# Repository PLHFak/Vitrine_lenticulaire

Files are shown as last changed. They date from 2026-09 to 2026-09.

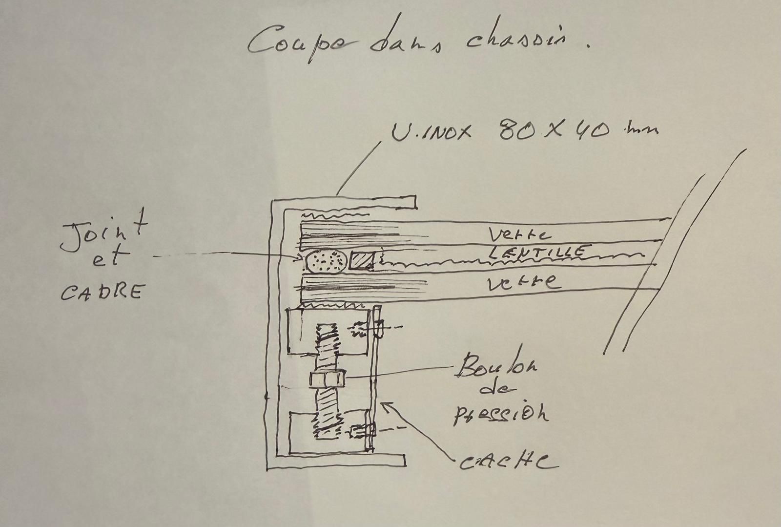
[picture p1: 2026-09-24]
img/croquis_260924.jpeg

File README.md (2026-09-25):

# La vitrine lenticulaire — Les Veilleurs

Note de principe et dossier de fabrication du double vitrage démontable de l'écran lenticulaire (site statique).

- `data.js` — tout le contenu : contexte, fiche, principe, montage, profil & vent, fournitures, points ouverts, documents, prompt CAO, journal
- `img/` — figures de principe, croquis, châssis v01, vues du STEP v00
- `docs/` — note v01 (PDF), note vent (MD), PDF cartouchés des schémas (`docs/pdf/`), CAO (`docs/cao/` : STEP v00 de J. Miceli, STL châssis v01), plans du socle
- `vercel.json` — déploiement Vercel (preset Other), noindex

Site : https://vitrine-lenticulaire.vercel.app (à importer sur Vercel depuis ce dépôt). Lien direct : https://vitrine-lenticulaire.vercel.app/?code=EVA

## Charte commune aux trois dossiers

Les trois sites (`Base_les_veilleurs`, `Vitrine_lenticulaire`, `Aquarium-K9`) partagent le même gabarit :

- `lv.css` et `lv.js` — styles, barre de titre (liens vers les trois dossiers, onglets de langue), cartouche technique, cartes « Documents ». **Ces deux fichiers doivent rester identiques dans les trois dépôts** : toute modification se recopie dans les deux autres.
- `data.js` — le seul fichier de contenu. Chaque texte est donné dans les quatre langues avec `L("fr","en","nl","de")` ; les schémas et plans restent légendés en français.
- `index.html` — gabarit et rendu des sections propres au dossier (ne porte pas de contenu).
- `build.py` — génère les vignettes (`docs/thumbs/`), les PDF avec cartouche des schémas (`docs/pdf/`), les PNG des plans (`docs/png/`) et `docs/sizes.js`. S'appuie sur `lv_build.py` (commun, identique dans les trois dépôts ; Pillow, reportlab, pdftoppm).

Langue : onglets FR / EN / NL / DE en haut de page, ou `?lang=en` dans le lien ; le choix est mémorisé dans le navigateur.

Accès : code `EVA` (côté client, `lv.js`), ou `?code=EVA` dans le lien. Pages en `noindex`.

## Mesure d'audience (chapitre « Fréquentation »)

- `api/hit.js` — reçoit les mesures du navigateur sur le même domaine que le site (rien vers un tiers ; échec silencieux). Pas d'IP ni de cookie : site, langue, page, document téléchargé, pays/ville (en-têtes Vercel), appareil, durée.
- `api/stats.js` — statistiques ; le code administrateur est vérifié dans la base (fonction `lv_stats`), jamais côté client.
- `api/_cfg.js` — URL et clé *anon* Supabase (variables Vercel `SUPABASE_URL` / `SUPABASE_ANON_KEY` prioritaires).
- `docs/lv_analytics.sql` — à exécuter une fois dans Supabase (tables `lv_hits`, `lv_config` avec le code administrateur, fonction `lv_stats`). Commun aux trois sites.
- Le chapitre apparaît en bas de page quand le site est ouvert avec le code administrateur (saisi au clavier ; il n'est jamais mis dans un lien). Les visites administrateur ne sont pas comptées.

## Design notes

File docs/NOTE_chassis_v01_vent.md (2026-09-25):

# Châssis vitrine lenticulaire — v01 et prise au vent (25-09-2026)

Transfert depuis le fil « base monobloc ». Fichiers dans ce dossier :
- `ecran_v00_100x40x3.stp` — STEP de Jacky (Inventor, 24-09-26) : tube 100×40×3, hors tout 1 890, montants 1 728 dont 528 traversants.
- `ecran_v00_vues.png` — filaire du STEP en 3 vues.
- `ecran_v01_U80x40.png` / `.stl` — châssis adapté : U 80×40×5 inox 316L, hors tout 1 820 × 1 220, verre 1 800 × 1 200, montants 1 720 dont 500 encastrés (réservation borgne 50×110×500, entraxe 1 780 — plan V00 à mettre à jour, 1 720 actuel).

## Profil
| Profil | W (cm³) | kg/m | Dispo |
|---|---|---|---|
| U 80×40×4 plié 316L | 14,7 | 4,8 | pliage sur mesure |
| **U 80×40×5 soudé laser 316L** | 17,7 | 5,9 | sur mesure, retenu |
| UPN 80 inox (80×45×6/8) | 26,5 | 8,6 | catalogue, plus lourd |

## Vent 220 km/h (61 m/s, q = 2,3 kPa, cf = 1,8 panneau isolé)
- Effort écran 9,6 kN à 0,66 m → 6,4 kNm ; par montant 4,8 kN / 3,2 kNm.
- Contraintes : U 4 mm 216 MPa (limite) ; U 5 mm 180 MPa (OK, 20 % de marge) ; UPN 80 120 MPa ; tube 100×40×3 162 MPa. Flèche en tête 7 mm (U 5 mm).
- Encastrement 500 mm : pression sur pierre ≈ 1,7 MPa, négligeable pour du Comblanchien.
- Bloc 6,7 t : renversement 12,5 kNm vs 62 kNm stabilisant → sécurité 5 ; glissement 33 kN vs 14 kN. Tient par sa masse.
- Verre : 55.2 recuit ≈ 23 MPa (limite) → prévoir feuilleté trempé (66.2 trempé ≈ 16 MPa).
- Prédimensionnement à confirmer par le bureau d'ossature.

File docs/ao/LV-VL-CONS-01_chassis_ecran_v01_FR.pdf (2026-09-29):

PROJET
LES VEILLEURS — Beaufort 27

ARTISTE · MAÎTRE D'ŒUVRE
Eva L'Hoest · +32 495 57 92 12 · eva.lhoest@gmail.com

ASSISTANT ÉLECTROMÉCANIQUE
Gioacchino Miceli · +32 497 84 45 10 gioacchino.miceli@thefaktory.com

Production Office
Eva L'Hoest / EHLAB SRL · eva.production.bx@gmail.com

DOCUMENT
Châssis de l'écran — consultation

OBJET
Châssis tube inox 316L, deux montants scellés

N° DOCUMENT
LV-VL-CONS-01

RÉVISION
v01.1

DATE · HEURE
29-09-2026 · 23:56

STATUT
CONSULTATION

PAGE
1 / 5

© Eva L'Hoest 2026 — Confidentiel. Reproduction, diffusion ou usage hors de cette consultation interdits sans accord écrit de l'artiste. Cotes non contractuelles.

## Les Veilleurs — Châssis de l'écran lenticulaire

Dossier de consultation v01 · septembre 2026 · métallerie inox — demande d'avis constructif et d'offre de prix

### 1. De quoi s'agit-il

Une œuvre d'art permanente sur la côte belge (Beaufort 27, mer du Nord), qui doit tenir au moins dix ans en milieu marin. Sur un socle monobloc en pierre claire se dresse un écran de 1,8 × 1,2 m : un panneau lenticulaire pris entre deux verres feuilletés, qui joue avec l'horizon. Nous cherchons un atelier pour fabriquer le châssis qui porte cet écran : un cadre rectangulaire en tube inox 316L, dont les deux montants sont prolongés et scellés dans le socle. C'est une pièce unique, simple à souder, faite pour durer dehors. Le vitrage n'est pas dans cette consultation. Les cotes ci-dessous sont notre proposition : votre avis sur ce qui est plus simple, plus sûr ou moins cher à fabriquer nous intéresse autant que votre prix.

### 2. Cotes principales

Élément | Cote / valeur | Remarque
Profil | tube rectangulaire 80 × 40 × 3 mm, inox 316L | grand côté (80) dans le sens du vent ; 4 mm acceptable si vous le jugez préférable, à indiquer
Largeur hors tout | 1 890 mm | entre montants : 1 810
Montants | 2 × 1 728 mm | 1 200 visibles + 528 scellés dans le socle
Traverse basse | 1 810 mm, soudée | son dessus affleure le dessus du socle
Traverse haute | 1 810 mm, rapportée | boulonnée après insertion du vitrage ; assemblage à proposer
Ouverture libre | 1 810 × 1 120 mm | reçoit un sandwich verre / lenticulaire / verre d'environ 30 mm
Réception du vitrage | à l'extérieur du tube, côté mer | proposition : parclose plat 40 × 6 vissée, bandes souples 2 mm, aucun contact verre / métal — voir § 3.3
Scellement | 2 réservations ≈ 50 × 90 × 528 dans la pierre | résine ou mortier de scellement ; taillées par l'atelier de pierre sur vos cotes finales
Masse | ≈ 37 kg (7,1 m de tube) | manutention à deux, sans engin
Finition | brossée, bouts de tube fermés | à échantillonner ; cordons visibles meulés et brossés

### 3. Description pièce par pièce

3.1 Montants et traverse basse — Trois tubes 80 × 40 × 3 en 316L, assemblés en U par deux soudures d'angle (onglet ou coupe droite, à votre choix), cordons continus, pénétration complète en pied de montant. Les montants sont fermés en tête et en pied par une plaque soudée de 3 mm ; aucune eau ne doit pouvoir entrer dans les tubes. La partie scellée (528 mm) peut rester brute ; deux goujons ou tiges soudés en travers améliorent l'ancrage dans la résine.
3.2 Traverse haute rapportée — Tube identique, fixé en tête des montants par un assemblage démontable (platines et boulons inox A4, ou embouts glissants goupillés). Il n'a pas besoin d'être rigide : une fois le vitrage serré, le sandwich triangule le cadre. L'assemblage doit rester discret vu de face : proposez-nous le vôtre.
3.3 Réception du vitrage (proposition) — Le sandwich verre / lenticulaire / verre (≈ 1 800 × 1 200 × 30 mm, ≈ 60 kg, fourni par le lot vitrage) vient s'appliquer contre la face extérieure du cadre, côté mer, sur une bande souple autocollante de 2 mm. Il est retenu par un cadre de parcloses en plat inox 40 × 6 vissé dans le tube (vis fraisées Torx A4, pas ≈ 200), avec une seconde bande souple entre la parclose et le verre. Aucune vis ne traverse le verre ; le vitrage reste démontable

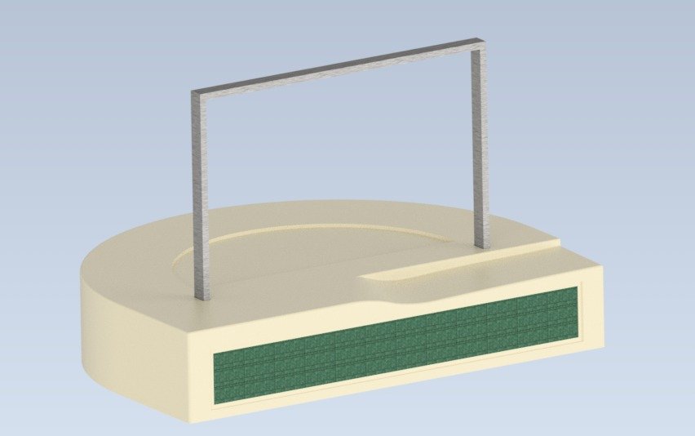
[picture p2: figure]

PROJET
LES VEILLEURS — Beaufort 27

ARTISTE · MAÎTRE D'ŒUVRE
Eva L'Hoest · +32 495 57 92 12 · eva.lhoest@gmail.com

ASSISTANT ÉLECTROMÉCANIQUE
Gioacchino Miceli · +32 497 84 45 10

DOCUMENT
Châssis de l'écran — consultation

OBJET
Châssis tube inox 316L, deux montants scellés

N° DOCUMENT
LV-VL-CONS-01

RÉVISION
v01.1

DATE · HEURE
29-09-2026 · 23:56

STATUT
CONSULTATION

PAGE
2 / 5

© Eva L'Hoest 2026 — Confidentiel. Reproduction, diffusion ou usage hors de cette consultation interdits sans accord écrit de l'artiste. Cotes non contractuelles.

sur place. Si vous connaissez une solution plus simple ou plus élégante (cornière, profil de battée, feuillard), elle est la bienvenue.
3.4 Tenue au vent et scellement — Front de mer : le châssis est tenu par l'encastrement des montants, pas par les angles du cadre. Le socle en pierre (≈ 6,7 t) reçoit deux réservations verticales de 528 mm ; le scellement se fait à la résine ou au mortier après réglage d'aplomb. Le prédimensionnement au vent a été fait par nos soins et sera confirmé par le bureau d'ossature ; si vous préférez une épaisseur de 4 mm, dites-le et chiffrez les deux.
3.5 Ce que nous vous demandons — Une offre en € HT pour la fourniture du châssis : tubes, traverse haute démontable, parcloses et bandes souples (ou votre alternative), certificat matière 3.1, finition. En option : transport et pose des montants dans le socle à Westende (scellement compris). Merci d'indiquer votre délai à partir de la commande, vos hypothèses et tout point du dossier qui vous paraît discutable.

### 4. Points ouverts

– Épaisseur du tube (3 ou 4 mm) : à votre appréciation, offre pour les deux bienvenue.
– Assemblage de la traverse haute : platines boulonnées ou embouts glissants.
– Détail de réception du vitrage : notre parclose 40 × 6 est une proposition ; votre solution habituelle nous intéresse. – Le sandwich vitré fera 29 ou 32 mm selon le verre retenu (55.2 ou 66.2) : la parclose doit s'en accommoder.
– Le socle est en cours d'étude ; les cotes de réservation seront figées avec le plan de socle V01.

Les plans de ce dossier ont été établis avec l'aide de l'intelligence artificielle, sous le contrôle de l'équipe. Nous sommes ouverts à vous confier le plan de réalisation, ou à travailler avec le bureau d'études que vous nous suggérez.

### 5. Figures

Fig. 1 — Rendu d'ensemble : socle, écran et niche des cristaux (les figures en bronze ne sont pas représentées).

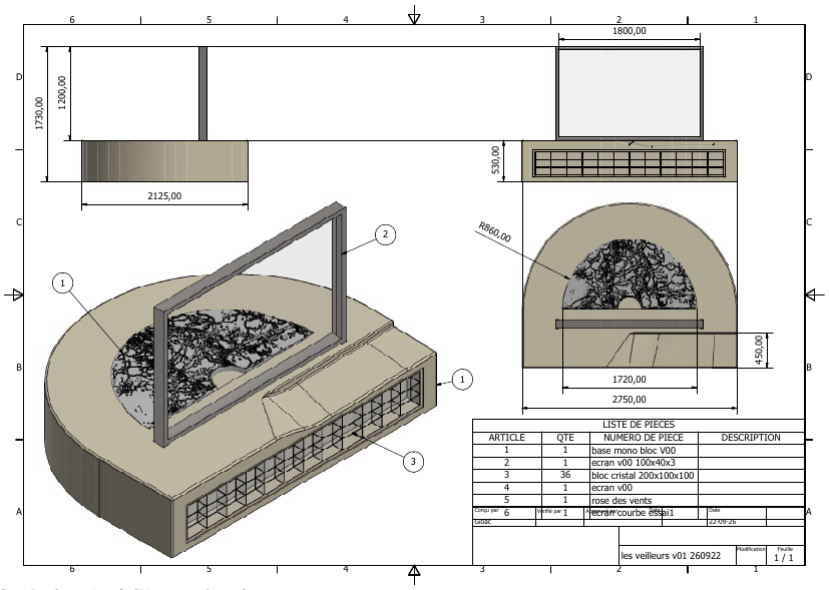
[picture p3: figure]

PROJET
LES VEILLEURS — Beaufort 27

ARTISTE · MAÎTRE D'ŒUVRE
Eva L'Hoest · +32 495 57 92 12 · eva.lhoest@gmail.com

ASSISTANT ÉLECTROMÉCANIQUE
Gioacchino Miceli · +32 497 84 45 10

DOCUMENT
Châssis de l'écran — consultation

OBJET
Châssis tube inox 316L, deux montants scellés

N° DOCUMENT
LV-VL-CONS-01

RÉVISION
v01.1

DATE · HEURE
29-09-2026 · 23:56

STATUT
CONSULTATION

PAGE
3 / 5

© Eva L'Hoest 2026 — Confidentiel. Reproduction, diffusion ou usage hors de cette consultation interdits sans accord écrit de l'artiste. Cotes non contractuelles.

Fig. 2 — Implantation de l'écran sur le socle.

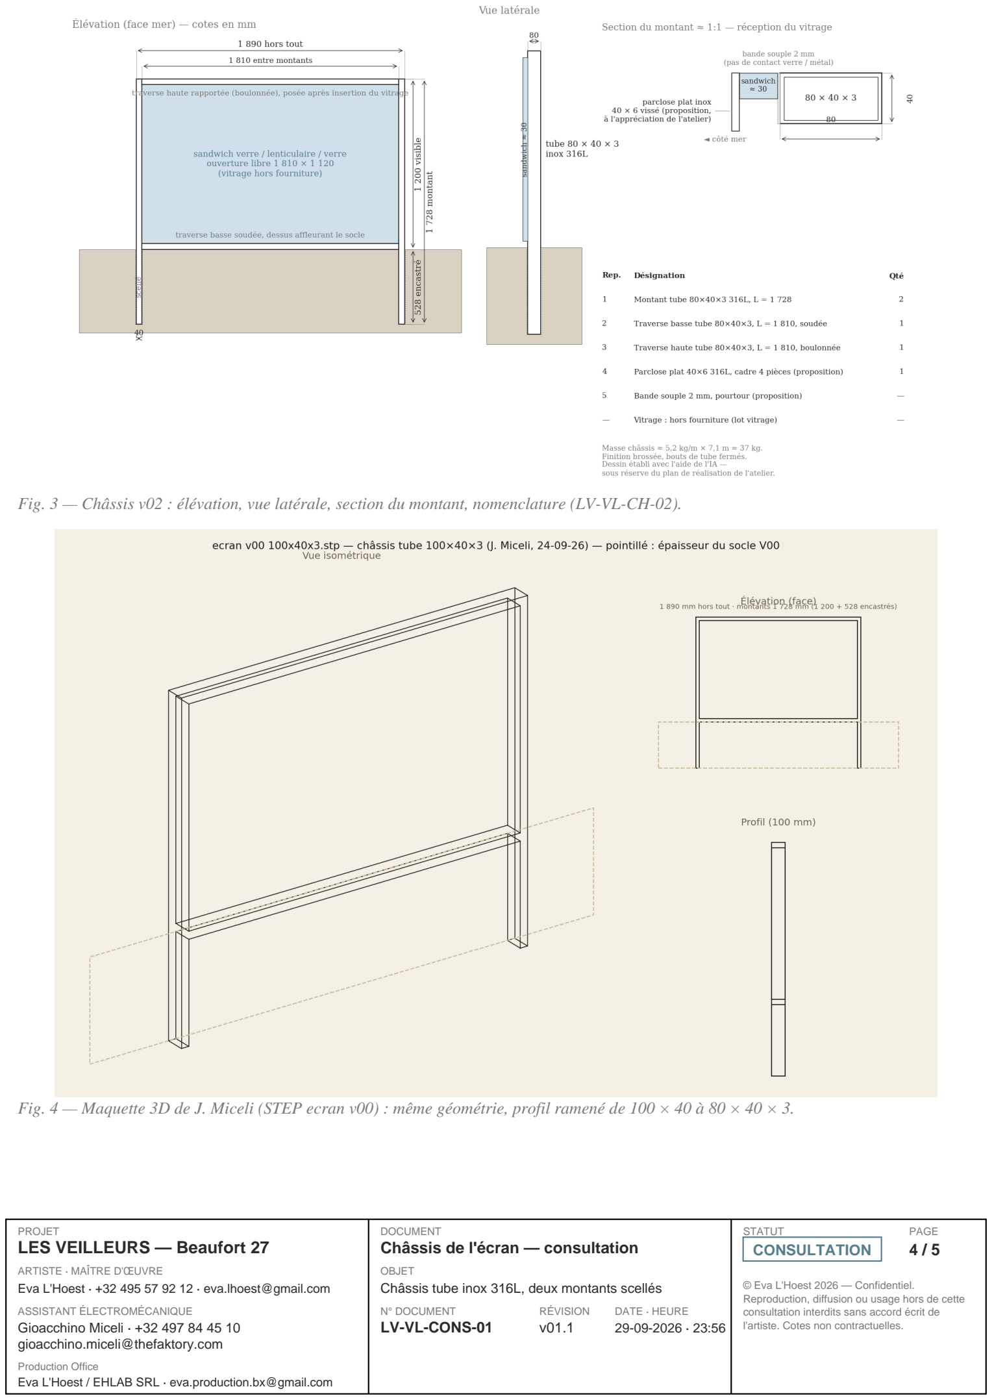
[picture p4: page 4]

PROJET
LES VEILLEURS — Beaufort 27

ARTISTE · MAÎTRE D'ŒUVRE
Eva L'Hoest · +32 495 57 92 12 · eva.lhoest@gmail.com

ASSISTANT ÉLECTROMÉCANIQUE
Gioacchino Miceli · +32 497 84 45 10

DOCUMENT
Châssis de l'écran — consultation

OBJET
Châssis tube inox 316L, deux montants scellés

N° DOCUMENT
LV-VL-CONS-01

RÉVISION
v01.1

DATE · HEURE
29-09-2026 · 23:56

STATUT
CONSULTATION

PAGE
4 / 5

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

Fig. 3 — Châssis v02 : élévation, vue latérale, section du montant, nomenclature (LV-VL-CH-02).

Fig. 4 — Maquette 3D de J. Miceli (STEP ecran v00) : même géométrie, profil ramené de 100 × 40 à 80 × 40 × 3.

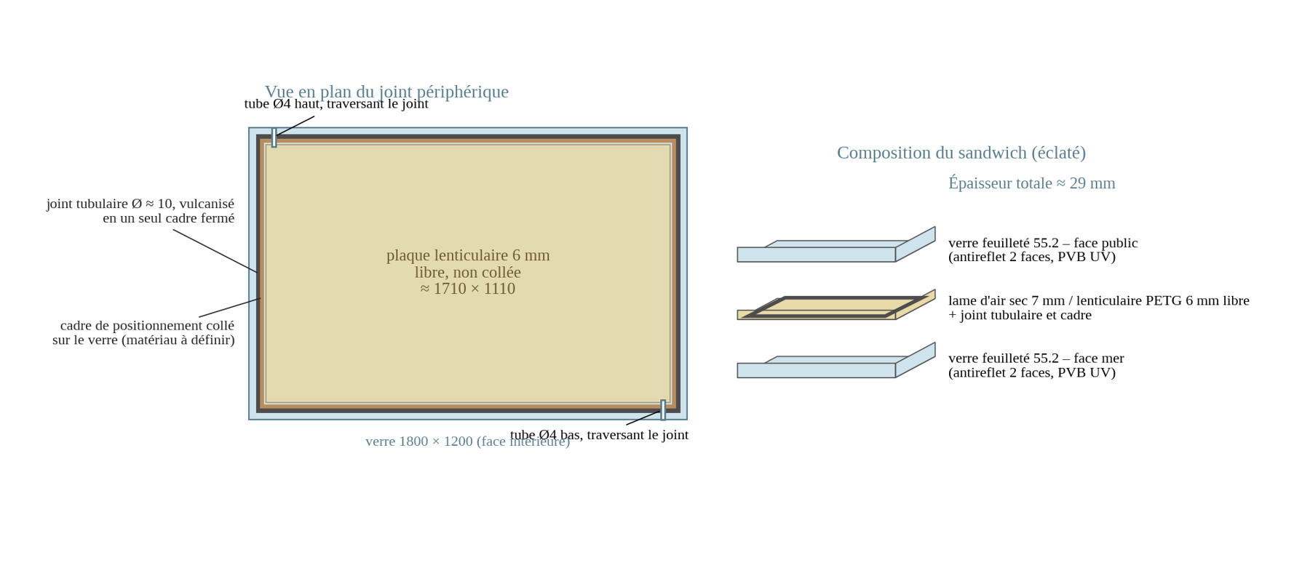
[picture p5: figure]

PROJET
LES VEILLEURS — Beaufort 27

ARTISTE · MAÎTRE D'ŒUVRE
Eva L'Hoest · +32 495 57 92 12 · eva.lhoest@gmail.com

ASSISTANT ÉLECTROMÉCANIQUE
Gioacchino Miceli · +32 497 84 45 10

DOCUMENT
Châssis de l'écran — consultation

OBJET
Châssis tube inox 316L, deux montants scellés

N° DOCUMENT
LV-VL-CONS-01

RÉVISION
v01.1

DATE · HEURE
29-09-2026 · 23:56

STATUT
CONSULTATION

PAGE
5 / 5

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

Fig. 5 — Le sandwich verre / lenticulaire / verre reçu par le châssis (pour information, lot vitrage).

### 6. Documents et liens

– Dossier Drive (présentation, plans, CAO) : https://drive.google.com/drive/folders/1gwChq_mJxhfM1suTWyyN8btA9JSbgtrG
– Site technique de la vitrine : https://vitrine-lenticulaire.vercel.app/?code=EVA
– Maquette 3D interactive de l'ensemble : https://base-les-veilleurs.vercel.app/monobloc.html?code=EVA
– Contact : Production Office — Eva L'Hoest / EHLAB SRL — eva.production.bx@gmail.com ; questions techniques : Gioacchino Miceli.

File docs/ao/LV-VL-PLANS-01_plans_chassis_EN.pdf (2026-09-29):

# Les Veilleurs — Screen frame — Drawings (LV-VL-PLANS-01, rev. 1, 29-09-2026)

# Set of drawings for the frame lot · drawings labelled in French

1. LV-VL-CH-02 | Frame v02, 80×40×3 tube 316L — elevation, side view, section, parts list
2. LV-VL-CAO-00 | STEP 'ecran v00' (J. Miceli) — three views (100×40 section, now 80×40×3)
3. LV-VL-FIG-01 | Principle elevation, dimensions in mm
4. LV-VL-FIG-03 | Glass / lenticular / glass sandwich (glazing lot, for information)
5. LV-VL-FIG-04 | Dry-air circuit, pressure-balancing pouch and desiccant (for information)
6. LV-VL-FIG-05 | Assembly sequence

Section fixed on 29-09-2026: rectangular tube 80 × 40 × 3 mm, 316L stainless (earlier sheets in U 80×40×5 and 100×40 tube are withdrawn).
Key French terms: montant = upright · traverse = rail · encastré / scellé = embedded / grouted · vitrage = glazing · parclose = glazing bead · socle = base · joint = gasket. Drawings prepared with the help of AI under the team's control — subject to the workshop's shop drawings. Dimensions not contractual.

© Eva L'Hoest 2026 — Confidentiel / Confidential. Cotes non contractuelles / Dimensions not contractual.

# Les Veilleurs — Vitrine lenticulaire — Châssis v02 tube 80×40×3 316L

## LV-VL-CH-02 · rév. 2 · 29-09-2026 · CONSULTATION · schéma légendé en français

PROJET

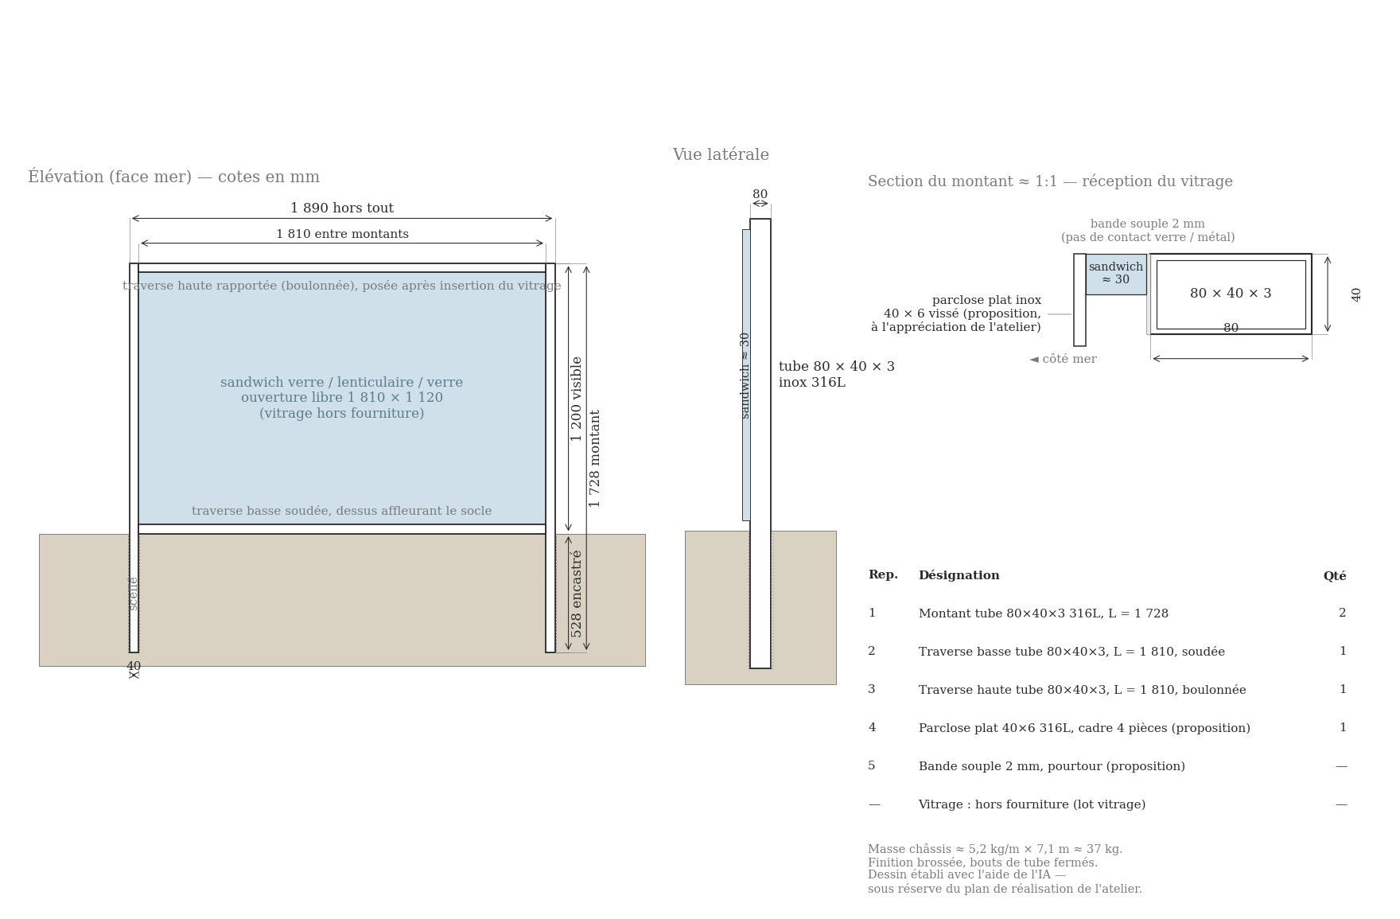
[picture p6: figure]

## LES VEILLEURS — Beaufort 27

ARTISTE · MAÎTRE D'ŒUVRE

## Eva L'Hoest · +32 495 57 92 12 · eva.lhoest@gmail.com

ASSISTANT ÉLECTROMÉCANIQUE

## Gioacchino Miceli · +32 497 84 45 10 · gioacchino.miceli@thefaktory.com

DOCUMENT

## Vitrine lenticulaire — Châssis v02 tube 80×40×3 316L

OBJET

## Châssis de l'écran : profil arrêté 80×40×3, géométrie selon STEP ecran v00 (J. Miceli)

N° DOCUMENT · RÉVISION · DATE · HEURE

## LV-VL-CH-02 · rév. 2 · 29-09-2026

EN LIGNE

### https://vitrine-lenticulaire.vercel.app

STATUT

## CONSULTATION

© Eva L'Hoest 2026 — Confidentiel. Reproduction, diffusion ou usage hors de cette consultation interdits sans accord écrit de l'artiste. Cotes non contractuelles.

Les Veilleurs — La vitrine lenticulaire — STEP « ecran v00 100x40x3 » (J. Miceli) — trois vues

## LV-VL-CAO-00 · rév. 0 · 24-09-26 · ÉTUDE · schéma légendé en français

PROJET

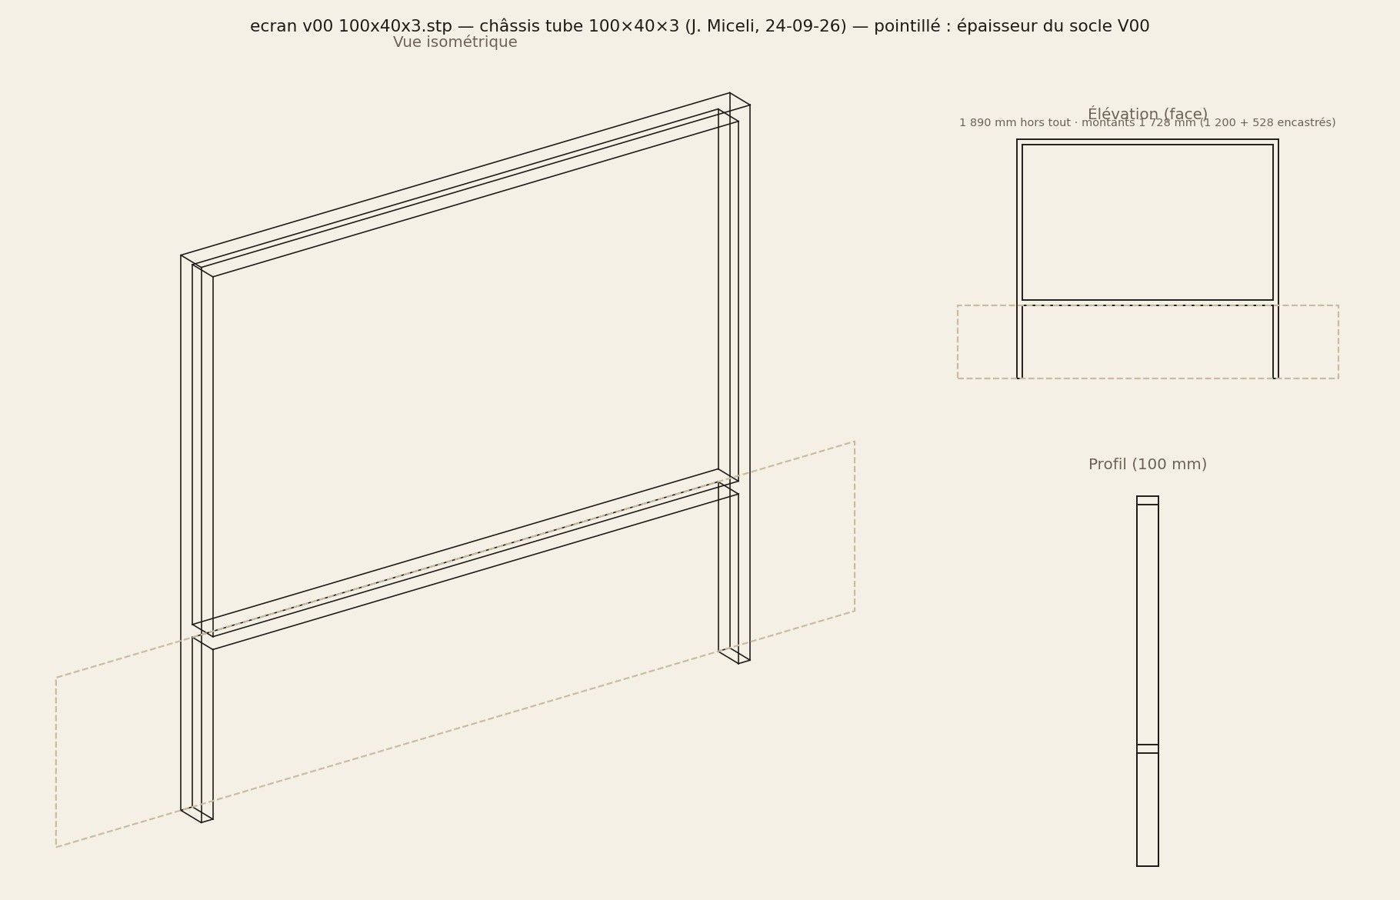
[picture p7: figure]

## LES VEILLEURS — Beaufort 27

ARTISTE · MAÎTRE D'ŒUVRE

## Eva L'Hoest · +32 495 57 92 12 · eva.lhoest@gmail.com

ASSISTANT ÉLECTROMÉCANIQUE

## Gioacchino Miceli · +32 497 84 45 10 · gioacchino.miceli@thefaktory.com

DOCUMENT

## La vitrine lenticulaire — STEP « ecran v00 100x40x3 » (J. Miceli) — trois vues

OBJET

## Double vitrage démontable, lenticulaire libre, châssis U inox

N° DOCUMENT · RÉVISION · DATE · HEURE

## LV-VL-CAO-00 · rév. 0 · 24-09-26

STATUT

## ÉTUDE

© Eva L'Hoest 2026 — Confidentiel. Reproduction, diffusion ou usage hors de cette consultation interdits sans accord écrit de l'artiste. Cotes non contractuelles.

# Les Veilleurs — La vitrine lenticulaire — Élévation, cotes en mm

## LV-VL-FIG-01 · rév. 1 · 24-09-26 · ESQUISSE · schéma légendé en français

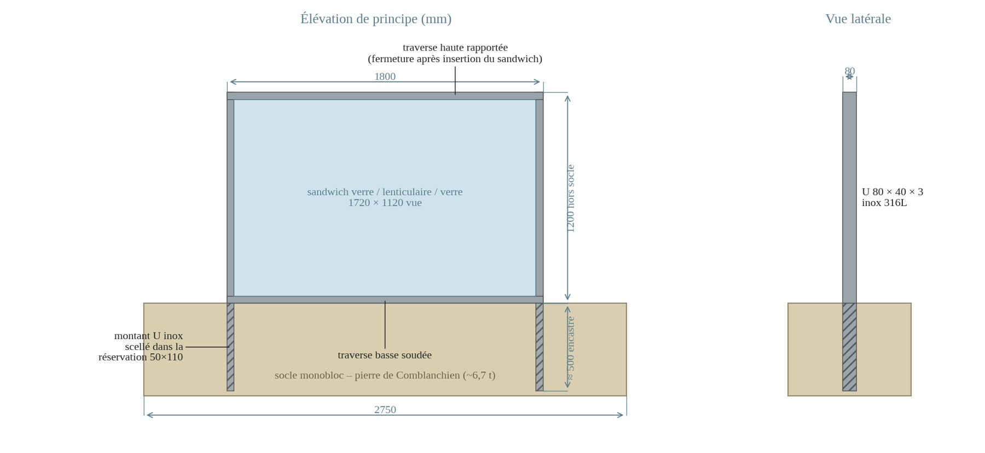
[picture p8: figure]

PROJET

## LES VEILLEURS — Beaufort 27

ARTISTE · MAÎTRE D'ŒUVRE

## Eva L'Hoest · +32 495 57 92 12 · eva.lhoest@gmail.com

ASSISTANT ÉLECTROMÉCANIQUE

## Gioacchino Miceli · +32 497 84 45 10 · gioacchino.miceli@thefaktory.com

DOCUMENT

## La vitrine lenticulaire — Élévation, cotes en mm

OBJET

## Double vitrage démontable, lenticulaire libre, châssis U inox

N° DOCUMENT · RÉVISION · DATE · HEURE

## LV-VL-FIG-01 · rév. 1 · 24-09-26

STATUT

## ESQUISSE

© Eva L'Hoest 2026 — Confidentiel. Reproduction, diffusion ou usage hors de cette consultation interdits sans accord écrit de l'artiste. Cotes non contractuelles.

# Les Veilleurs — La vitrine lenticulaire — Le sandwich verre / lenticulaire / verre

## LV-VL-FIG-03 · rév. 1 · 24-09-26 · ESQUISSE · schéma légendé en français

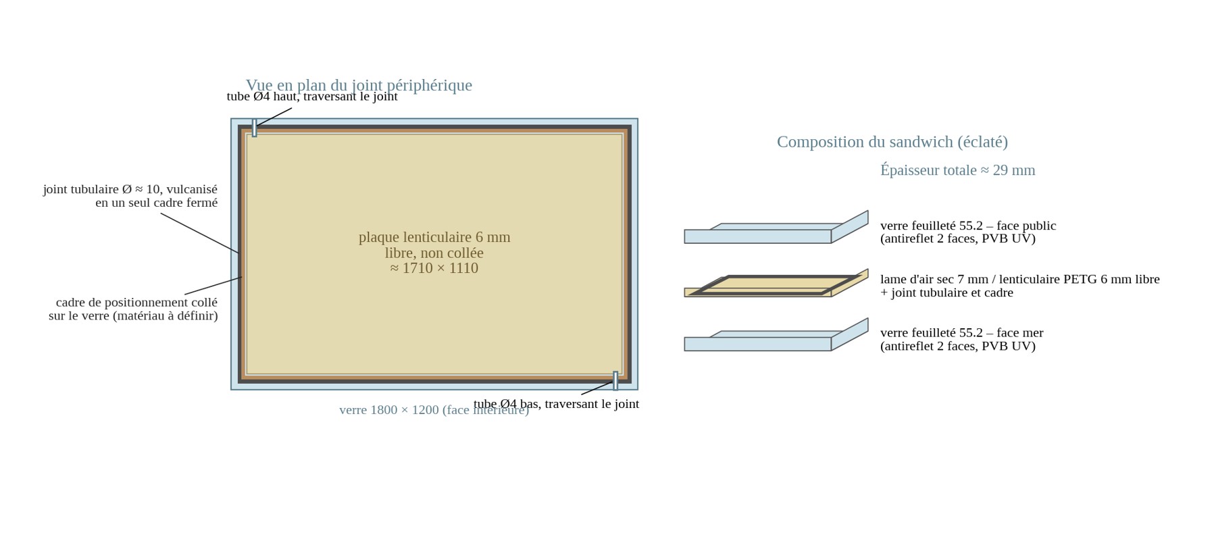
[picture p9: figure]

PROJET

## LES VEILLEURS — Beaufort 27

ARTISTE · MAÎTRE D'ŒUVRE

## Eva L'Hoest · +32 495 57 92 12 · eva.lhoest@gmail.com

ASSISTANT ÉLECTROMÉCANIQUE

## Gioacchino Miceli · +32 497 84 45 10 · gioacchino.miceli@thefaktory.com

DOCUMENT

## La vitrine lenticulaire — Le sandwich verre / lenticulaire / verre

OBJET

## Double vitrage démontable, lenticulaire libre, châssis U inox

N° DOCUMENT · RÉVISION · DATE · HEURE

## LV-VL-FIG-03 · rév. 1 · 24-09-26

STATUT

## ESQUISSE

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

Les Veilleurs — La vitrine lenticulaire — Circuit d'air sec, poche d'équilibrage et dessiccant

## LV-VL-FIG-04 · rév. 1 · 24-09-26 · ESQUISSE · schéma légendé en français

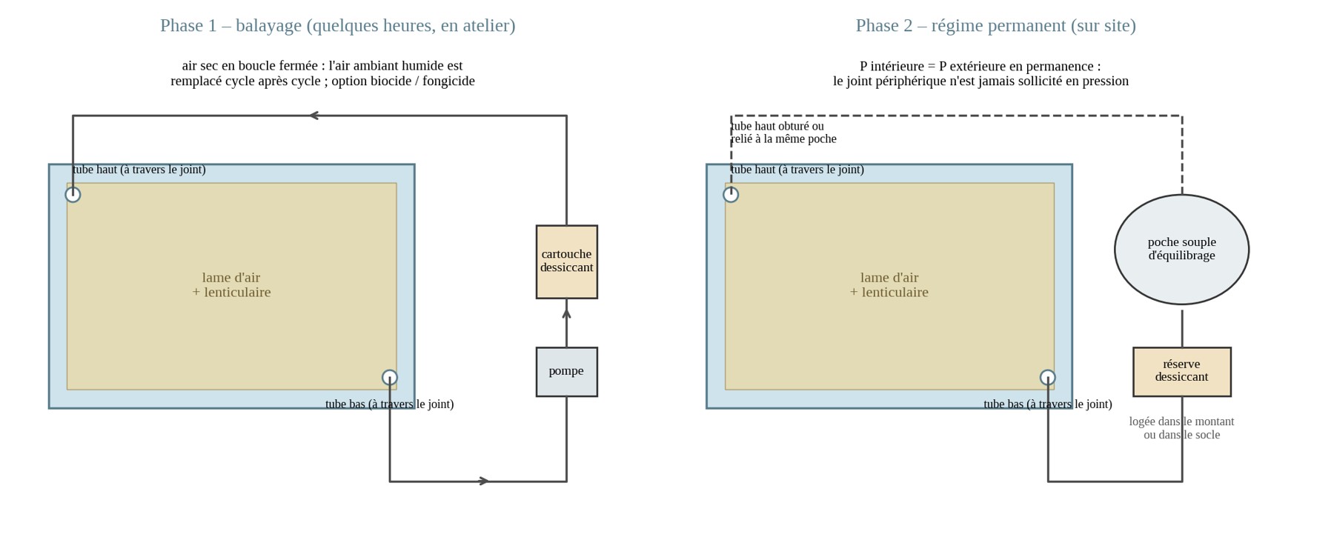
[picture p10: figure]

PROJET

## LES VEILLEURS — Beaufort 27

ARTISTE · MAÎTRE D'ŒUVRE

## Eva L'Hoest · +32 495 57 92 12 · eva.lhoest@gmail.com

ASSISTANT ÉLECTROMÉCANIQUE

## Gioacchino Miceli · +32 497 84 45 10 · gioacchino.miceli@thefaktory.com

DOCUMENT

## La vitrine lenticulaire — Circuit d'air sec, poche d'équilibrage et dessiccant

OBJET

## Double vitrage démontable, lenticulaire libre, châssis U inox

N° DOCUMENT · RÉVISION · DATE · HEURE

## LV-VL-FIG-04 · rév. 1 · 24-09-26

STATUT

## ESQUISSE

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

# Les Veilleurs — La vitrine lenticulaire — Séquence de montage

## LV-VL-FIG-05 · rév. 1 · 24-09-26 · ESQUISSE · schéma légendé en français

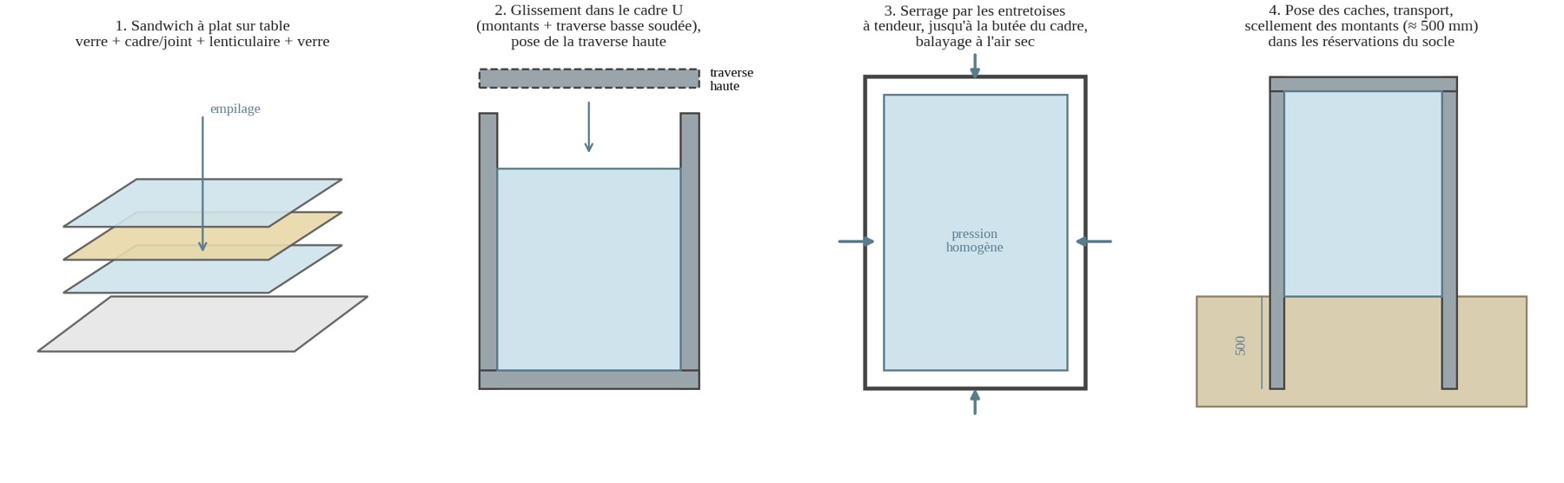
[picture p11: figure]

PROJET

## LES VEILLEURS — Beaufort 27

ARTISTE · MAÎTRE D'ŒUVRE

## Eva L'Hoest · +32 495 57 92 12 · eva.lhoest@gmail.com

ASSISTANT ÉLECTROMÉCANIQUE

## Gioacchino Miceli · +32 497 84 45 10 · gioacchino.miceli@thefaktory.com

DOCUMENT

## La vitrine lenticulaire — Séquence de montage

OBJET

## Double vitrage démontable, lenticulaire libre, châssis U inox

N° DOCUMENT · RÉVISION · DATE · HEURE

## LV-VL-FIG-05 · rév. 1 · 24-09-26

STATUT

## ESQUISSE

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

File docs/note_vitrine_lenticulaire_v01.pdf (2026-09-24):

Les Veilleurs – Eva L'Hoest / EHlab – Beaufort 27, Westende | Note de principe – vitrine lenticulaire – 24 septembre 2026

# Vitrine lenticulaire – châssis à serrage périphérique

Note de principe constructif – version 01 (esquisse), à valider par l'artiste

### 1. Objet et parti pris

L'écran de Les Veilleurs est un panneau lenticulaire de 1 800 × 1 200 mm dressé face à la mer sur le socle monobloc en pierre de Comblanchien. Exposé en permanence au vent, au sel, à la pluie et au rayonnement UV, le film lenticulaire ne peut être laissé nu. Le principe retenu est de le pincer, sans le coller, entre deux verres feuilletés qui assurent ensemble la rigidité, la protection mécanique, l'étanchéité aux intempéries et le filtrage des UV. Les deux verres sont eux-mêmes maintenus par un châssis inox en U qui exerce une pression périphérique homogène : un double vitrage démontable, construit et non manufacturé.

Pourquoi cette solution plutôt qu'un double vitrage industriel ou un collage ?

– Un vitrier ne peut pas, à coût raisonnable, insérer une plaque lenticulaire dans la fabrication d'un double vitrage scellé.
– Le PETG lenticulaire et le verre n'ont pas le même coefficient de dilatation : un collage finirait par se décoller partiellement et faire apparaître des zones grisées. La plaque est donc laissée libre et simplement tenue sur son pourtour. L'essai d'atelier sur 1 m² a confirmé que le film conserve son effet optique tenu mécaniquement.
– Un assemblage par serrage se démonte sur place : le panneau lenticulaire reste remplaçable et l'intérieur reste accessible pour l'entretien, ce qu'aucune solution scellée ne permet.

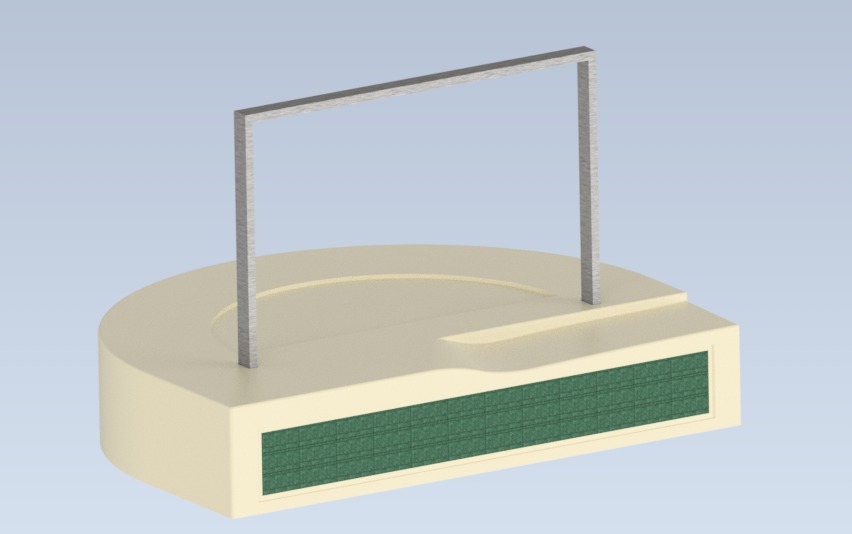
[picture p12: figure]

Fig. 0 – Maquette 3D de l'ensemble (Jacky, 22-09-26) : socle, niche des cristaux et cadre de l'écran. Les trois figures en bronze ne sont pas représentées.

### 2. Composition du sandwich

De la face public vers la mer : verre feuilleté de sécurité 55.2 – lame d'air sec contenant la plaque lenticulaire – verre feuilleté de sécurité 55.2. Épaisseur totale d'environ 29 mm.

– Verre 55.2 (2 × 5 mm + 2 PVB) : choisi pour la résistance au vent et la sécurité du public ; en cas de bris, le film PVB retient les fragments. Le PVB assure par lui-même l'essentiel du filtrage UV nécessaire au lenticulaire.
– Antireflet sur les faces extérieures : le niveau de lumière en bord de mer est élevé ; sans antireflet, les reflets du ciel effaceraient l'effet d'invisibilité recherché. Traitement à valider sur échantillon avec l'artiste.
– Plaque lenticulaire PETG 6 mm (20 LPI), libre entre les deux verres, dimension légèrement inférieure au cadre intérieur pour laisser jouer la dilatation. Les rainures lenticulaires créent d'elles-mêmes une lame d'air ; c'est cette lame d'air qu'il faut protéger. La lame d'air entre les verres fait environ 7 mm.
– Joint tubulaire souple d'environ 10 mm de diamètre, vulcanisé en un seul cadre fermé, posé sur le pourtour entre les deux verres, comprimé à la hauteur de la lame d'air (≈ 30 %) : c'est lui qui rend le dispositif étanche.

– Cadre de positionnement (matériau à définir : PVC, PE ou aluminium anodisé), collé sur l'un des verres, juste à l'intérieur du joint. Il tient le joint en place pendant la fermeture – il ne peut fuir ni vers l'extérieur ni vers l'intérieur – et sert de butée d'écrasement : il limite le rapprochement des deux verres et garantit une compression homogène du joint sur tout le périmètre.

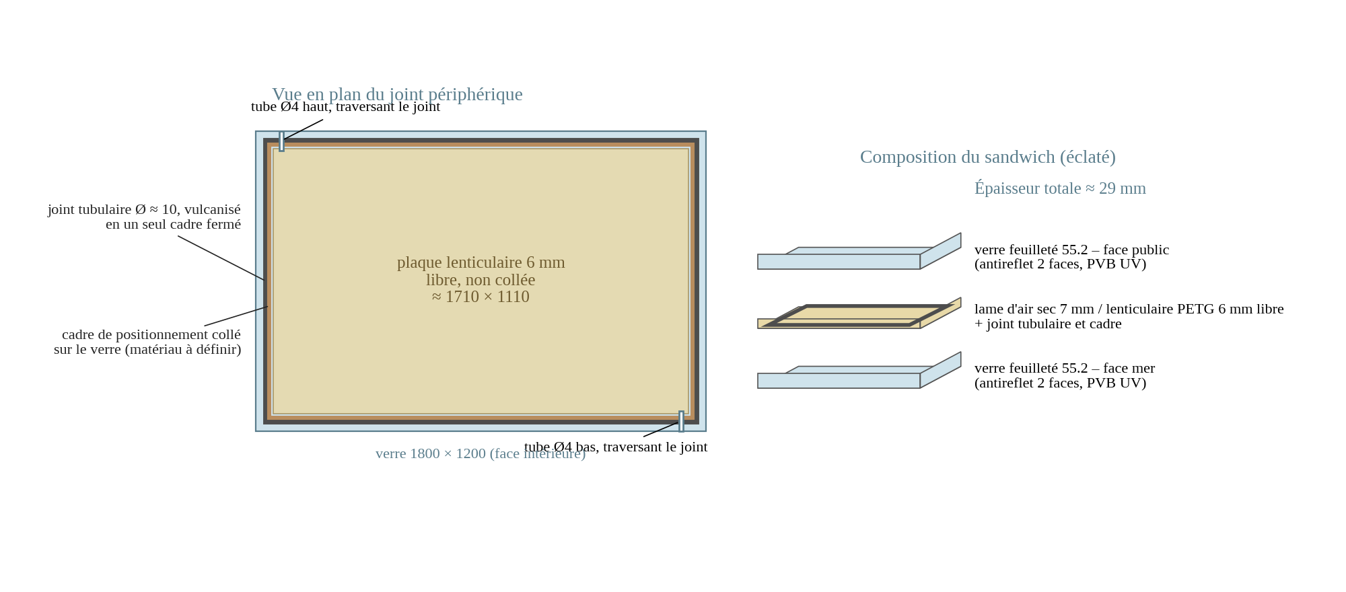
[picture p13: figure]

Fig. 1 – Joint périphérique en plan et composition du sandwich.

### 3. Lame d'air : condensation et prolifération

Une lame d'air enfermée avec l'humidité ambiante finit toujours par condenser et par accueillir algues ou moisissures. Deux dispositifs y répondent.

Balayage à l'air sec

Deux petits tubes d'environ 4 mm traversent le joint périphérique, dans la zone masquée par le châssis, l'un en bas, l'autre en haut : aucun perçage dans le verre. Après fermeture du sandwich, une petite pompe fait circuler pendant quelques heures de l'air passé sur cartouche dessiccante : cycle après cycle, l'air ambiant humide est remplacé par de l'air sec. On peut, au même moment, injecter un agent antibactérien et fongicide, ou un gaz inerte (azote sec, comme retenu pour la vitrine des cristaux).

Poche d'équilibrage de pression

Un vitrage scellé « respire » avec la température : la pression intérieure monte au soleil, descend la nuit, et le joint travaille en permanence. Ici, le réseau reste relié à une poche souple logée dans le montant ou dans le socle, contenant une réserve de dessiccant remplaçable. La poche se gonfle et se dégonfle avec la lame d'air : la pression intérieure est toujours égale à la pression extérieure, le joint périphérique n'est sollicité ni en pression ni en dépression, et aucun appel d'air ne se crée sur le pourtour.

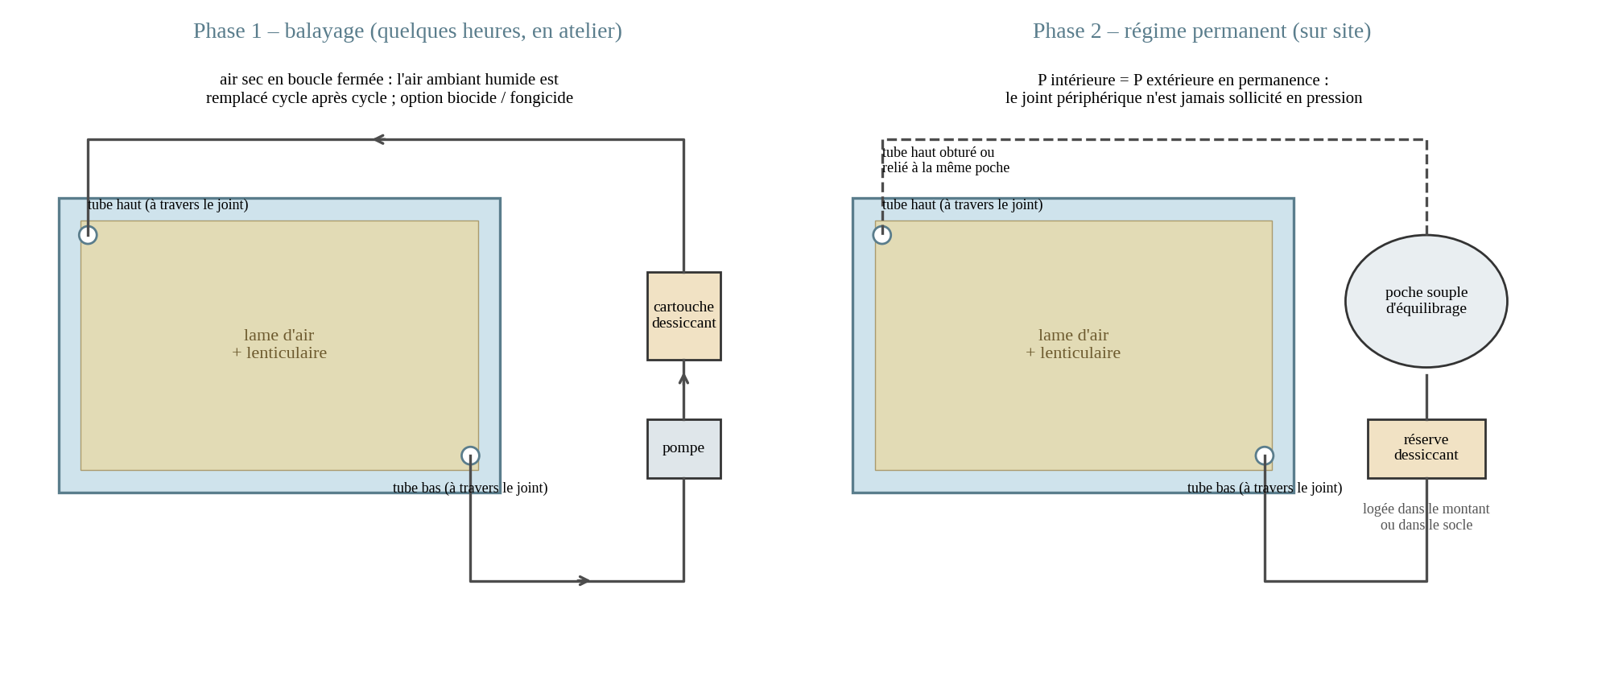
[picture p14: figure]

Fig. 2 – Circuit d'air sec : balayage en atelier, puis équilibrage permanent sur site.

### 4. Le châssis

Le châssis est un cadre en profil U inox 316L 80 × 40 × 3 mm (schéma de principe) ; la maquette 3D actuelle est en 100 × 40 × 3. La section peut être augmentée si le calcul au vent l'exige, mais l'artiste préfère rester dans des dimensions discrètes – ce point sera tranché par le bureau d'études.

– Traverse basse soudée aux deux montants ; traverse haute rapportée, fixée après insertion du sandwich. L'assemblage du montant haut (coupe à 45° ou en dépose) n'a pas besoin d'être rigide : la triangulation apportée par les verres suffit à rendre l'ensemble parfaitement stable.
– Montants prolongés d'environ 500 mm et scellés dans les réservations 50 × 110 mm du socle (monobloc d'environ 6,7 t) : la résistance au vent est assurée par l'encastrement, pas par les angles du cadre.
– Entretoises de pression logées dans le U, sur le côté opposé au vitrage : deux poussoirs taraudés, l'un à filet droit, l'autre à filet gauche, écartés par une tige filetée à pas contraires (principe du ridoir de hauban ou du tire-fort) ; un tour de tige écarte les deux poussoirs ensemble. Le poussoir inférieur est collé au double face sur l'aile du profil. Leur serrage plaque le sandwich contre l'aile opposée et met le joint en compression, jusqu'à la butée du cadre intérieur. Ces éléments sont à choisir parmi la quincaillerie existante.
– Rubans de joint souple mince entre le verre et l'aile du U d'un côté, entre le verre et l'entretoise de l'autre : ils calent le vitrage tout en lui laissant glisser pour absorber la dilatation différentielle verre / inox.
– Cache de finition clipsé sur l'ouverture du U, masquant les entretoises.

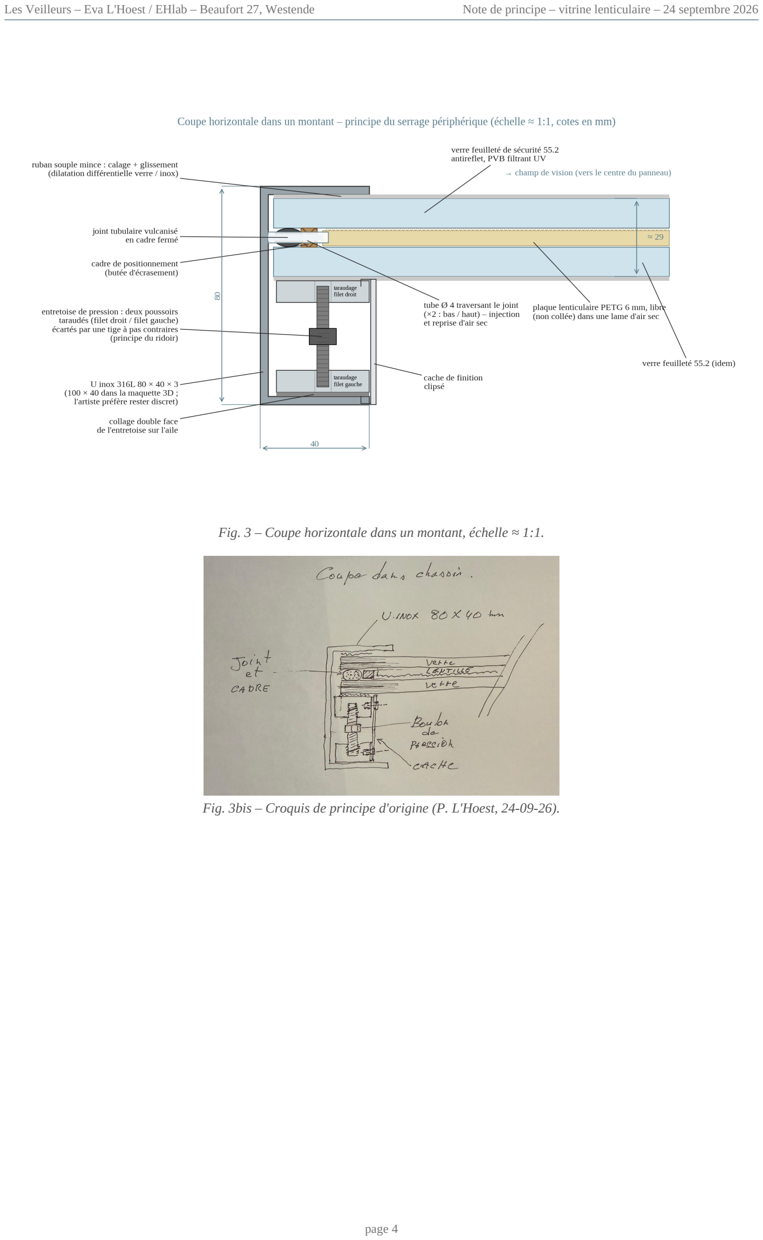
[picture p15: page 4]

Fig. 3 – Coupe horizontale dans un montant, échelle ≈ 1:1.

Fig. 3bis – Croquis de principe d'origine (P. L'Hoest, 24-09-26).

### 5. Montage et pose

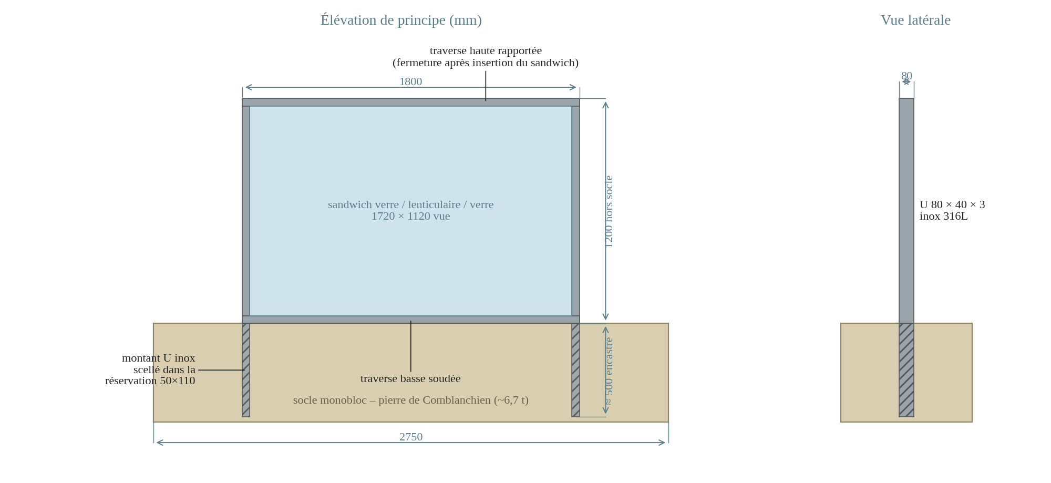
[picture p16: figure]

Fig. 4 – Élévation et vue latérale, cotes en mm.

– En atelier, à plat sur table : premier verre, cadre de positionnement collé, joint tubulaire posé dans son logement, plaque lenticulaire déposée libre, second verre.
– Le sandwich est glissé dans les U des montants et de la traverse basse ; la traverse haute est fixée pour fermer le cadre.
– Les entretoises sont serrées progressivement, en croix, en vérifiant l'écartement des deux verres afin de ne pas dépasser la butée du cadre intérieur : la pression doit rester homogène sur tout le périmètre.
– Balayage à l'air sec (quelques heures), raccordement de la poche d'équilibrage, contrôle d'étanchéité, pose des caches.
– Transport vertical, puis scellement des deux montants dans les réservations du socle. Si le châssis est livré à l'atelier avant le socle, il peut être noyé dans la masse et vitré sur place, comme envisagé pour la niche des cristaux.

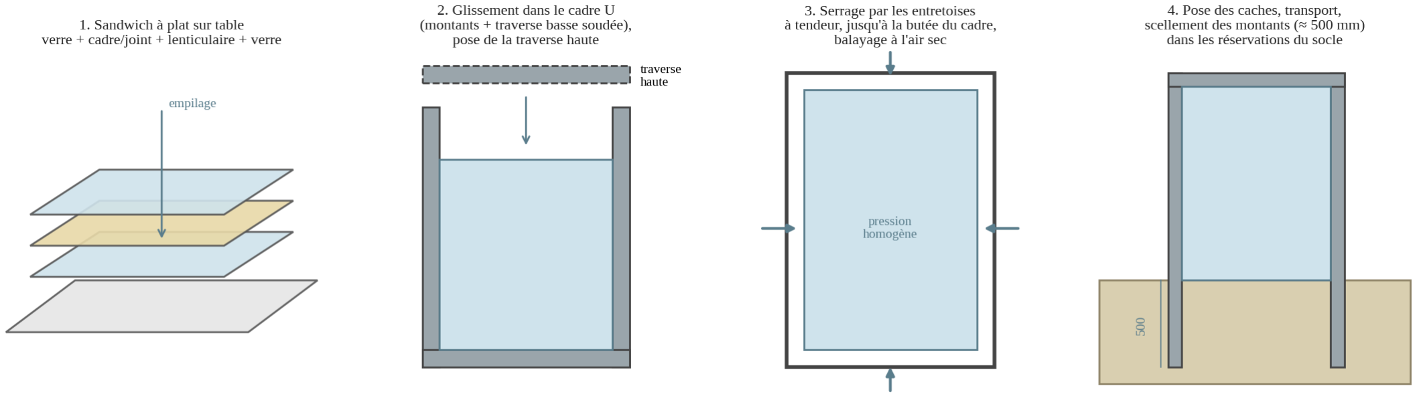
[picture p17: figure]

Fig. 5 – Séquence de montage.

### 6. Un dispositif unique, artisanal et entretenable

Il ne s'agit pas d'un produit à industrialiser mais d'une pièce unique, qui peut rester artisanale. La mise en œuvre est fastidieuse, mais ce n'est pas un handicap pour un exemplaire. En contrepartie, la construction offre ce qu'aucun vitrage scellé ne donne : elle se démonte sur place, l'intérieur reste accessible en cas de défaut, la plaque lenticulaire est remplaçable à moindre frais si elle venait à vieillir – essentiellement par protection UV insuffisante – et une maintenance préventive est possible sans démontage : remplacement de la réserve de dessiccant, ré-injection d'air sec ou de produits antibactériens et fongicides.

### 7. Points ouverts

– Section du profil : 80 × 40 ou 100 × 40, selon calcul au vent (Beaufort 27, front de mer).
– Hauteur du cadre de positionnement à caler sur l'épaisseur réelle du lenticulaire (6 mm) et sur la compression du joint (≈ 30 % pour Ø10).
– Matériau du cadre de positionnement et colle compatible PVB / PETG.
– Choix du fluide de balayage (air sec, azote) et de l'agent biocide compatible avec le PETG.
– Emplacement de la poche d'équilibrage (montant creux ou réservation dans le socle) et accès pour l'entretien. – Passage étanche des deux tubes à travers le joint tubulaire (traversée vulcanisée ou collée).
– Validation sur prototype grandeur réelle avant toute commande, comme convenu avec l'artiste.

### Annexe – Prompt pour la mise au net des dessins (PDF, puis STEP)

À coller dans un outil de CAO assisté (Fusion 360 / Onshape avec assistant, ou un agent de génération CadQuery / FreeCAD) avec, en pièces jointes, le croquis à main levée, les planches Inventor de Jacky et la présente note.

Contexte. Œuvre d'art permanente en front de mer (Westende, Belgique). Modéliser l'assemblage d'une vitrine lenticulaire : un sandwich verre / lenticulaire / verre de 1800 × 1200 mm maintenu par un châssis inox en U, encastré 500 mm dans un socle en pierre. Livrable 1 : planche PDF A3 (élévation, vue latérale, coupe horizontale dans un montant échelle 1:1, coupe verticale dans la traverse basse, éclaté d'assemblage, nomenclature). Livrable 2 : assemblage STEP AP214 paramétrique, une pièce par composant, cotes en mm.

Composants et cotes.
1. Verre feuilleté 55.2 (5 + 0,76 + 5 = 10,76 mm), 1800 × 1200, × 2, antireflet, sans perçage.
2. Plaque lenticulaire PETG 6 mm, 1710 × 1110, libre, centrée entre les verres.
3. Joint tubulaire souple Ø10, cadre fermé rectangulaire, axe à 45 mm du bord du verre, comprimé à 7 mm ; deux tubes Ø4 le traversent (un en bas à droite, un en haut à gauche).
4. Cadre de positionnement, section 6 × 7 mm, cadre fermé juste à l'intérieur du joint, collé sur le verre côté socle.
5. Profil U inox 316L 80 × 40 × 3 (paramètre : hauteur d'âme 80 ou 100), ouverture du U vers le centre du panneau ; deux montants de 1200 + 500 mm, traverse basse de 1800 mm soudée, traverse haute de 1800 mm rapportée (boulonnée, coupe droite).
6. Ruban souple 1,5 mm entre le verre et l'aile du U, et entre le verre et l'entretoise.
7. Entretoises de pression : deux poussoirs de 8 mm d'épaisseur sur toute la profondeur libre du U, chacun taraudé (M6 filet droit dans l'un, M6 filet gauche dans l'autre), écartés par une tige filetée à pas contraires avec six pans central (type ridoir) ; une entretoise tous les 300 mm sur le périmètre ; le poussoir inférieur est collé sur l'aile du U.
8. Cache de finition clipsé de 2 mm fermant l'ouverture du U sur la hauteur des entretoises.
9. Circuit d'air : deux tubes Ø4 partant des traversées du joint, cheminant dans le U, jusqu'à une poche souple (représenter par un volume de 1 L) et une cartouche de dessiccant logées dans le montant droit sous le niveau du socle.
10. Socle : représenter seulement une portion du monobloc (2750 × 527 × 400 mm) avec deux réservations 50 × 110 × 500 mm pour les montants, entraxe 1760 mm.

Règles. Le sandwich est plaqué contre l'aile du U côté extérieur, les entretoises côté intérieur. Aucun collage entre lenticulaire et verre, aucun perçage du verre. Cotes fonctionnelles à faire apparaître : 1800, 1200, 500, 80 (ou 100), 40, épaisseur sandwich ≈
29. Nommer les pièces en français. Produire d'abord la planche PDF pour validation, puis le STEP.

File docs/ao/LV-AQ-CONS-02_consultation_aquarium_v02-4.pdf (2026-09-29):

PROJET
LES VEILLEURS — Beaufort 27

ARTISTE · MAÎTRE D'ŒUVRE
Eva L'Hoest · +32 495 57 92 12 · eva.lhoest@gmail.com

ASSISTANT ÉLECTROMÉCANIQUE
Gioacchino Miceli · +32 497 84 45 10 gioacchino.miceli@thefaktory.com

DOCUMENT
Vitrine des cristaux — consultation

OBJET
Caisson inox, couvercle vitré, joint

N° DOCUMENT
LV-AQ-CONS-02

RÉVISION
v02.3

DATE · HEURE
25-09-2026 · 03:10

STATUT
CONSULTATION

PAGE
1 / 9

© Eva L'Hoest 2026 — Confidentiel. Reproduction, diffusion ou usage hors de cette consultation interdits sans accord écrit de l'artiste. Cotes non contractuelles.

# Les Veilleurs — Vitrine « aquarium » des cristaux

Dossier de consultation v02.3 · septembre 2026 · menuiserie métallique inox / chaudronnerie — demande d'avis constructif et d'estimation de prix

## 1. De quoi s'agit-il

Une œuvre d'art permanente sur la côte belge (Beaufort 27, mer du Nord). Dans son socle en pierre, une niche présente 33 blocs de cristal optique gravés au laser, posés sur fond noir derrière une vitre, dans une atmosphère d'azote sec qui les protège de l'humidité marine. Nous cherchons un atelier pour fabriquer cette niche : un caisson inox soudé étanche et son couvercle vitré démontable. C'est une pièce unique, artisanale, faite pour durer au
moins dix ans dehors et pour être ouverte et entretenue sur place. Les cotes ci-dessous sont notre proposition ; votre avis sur ce qui est plus simple, plus sûr ou moins cher à fabriquer nous intéresse autant que votre prix.

## 2. Cotes principales

Élément | Cote / valeur | Remarque
Cavité intérieure utile L × H × P | 2 204 × 333 × ~106 mm | 11 blocs de 200 par banc + 4 mm de cales ; 3 bancs de 100 + 3 mm de jeu haut + 30 mm de réserve ; profondeur : fond noir 4 + mousse comprimée 8 + bloc 100 − les blocs affleurent la vitre, 6 mm devant la face du cadre
Caisson hors tout (tôle) | 2 324 × 453 × ~138 mm | = cadre plat 60 mm autour de la cavité ; 138 = tôle → face avant du longeron = face de la pierre
Niche dans le socle de pierre | battée ≈ 64 × 32 sur tout le pourtour | le caisson est noyé dans la pierre ; la battée reçoit le cadre + longeron (jeu 4 mm), la face de la pierre affleure la vitre
Cadre visible en façade | 60 mm | l'artiste souhaite le plus discret possible : 50 mm bienvenu si la battée le permet
Vitre feuilletée extra-claire 66.2, antireflet | ≈ 2 264 × 393 × 13 mm — ≈ 29 kg | 2 × 6 mm bas fer + PVB ; couche antireflet sur la face extérieure ; bords polis
Blocs de cristal K9 | 33 × (200 × 100 × 100) — ≈ 166 kg | fournis et posés par nous, sur site
Masse chargée | ≈ 350 kg | caisson ≈ 60, cadre ≈ 26, longerons ≈ 63, vitre ≈ 29, blocs ≈ 166
Vis de serrage | ≈ 110 × M4×30 fraisées Torx, pas 50 | aucune vis ne traverse le verre
Étanchéité | toron EPDM Ø10 écrasé à ~30 % dans une gorge de 2 mm | la butée du longeron calibre l'écrasement, pas le couple de vissage

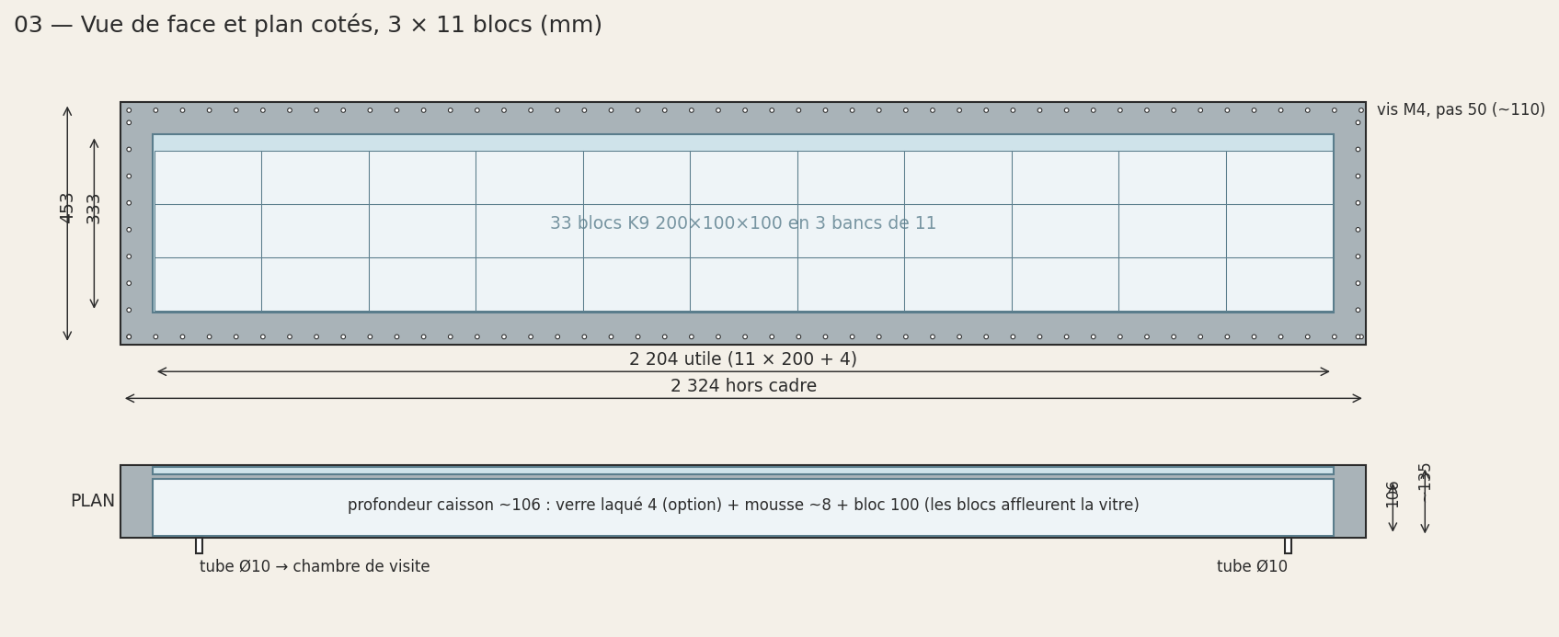
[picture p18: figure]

PROJET
LES VEILLEURS — Beaufort 27

DOCUMENT
Vitrine des cristaux — consultation

STATUT
CONSULTATION

PAGE
2 / 9

PROJET

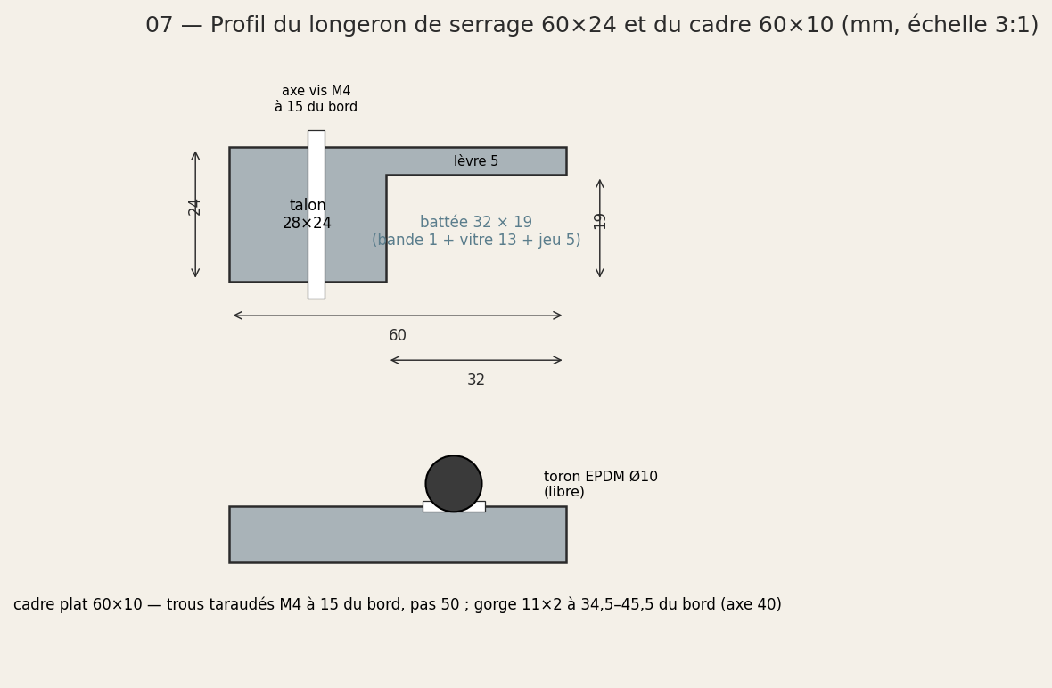
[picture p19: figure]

LES VEILLEURS — Beaufort 27

DOCUMENT
Vitrine des cristaux — consultation

STATUT
CONSULTATION

PAGE
3 / 9

## 3. Description pièce par pièce

3.1 Caisson (inox 316L, tôle 3 mm) — Tôle pliée en U (fond arrière + parois haute et basse), rayon intérieur ≤ 3 mm. Deux flasques d'extrémité 3 mm soudées en cordon continu, cordons intérieurs meulés à ras : la cavité doit rester lisse, les blocs glissent contre les parois. Raidisseurs à l'extérieur uniquement : 3 cornières horizontales et 4 verticales 40×40×4 soudées par points (30/150). Le fond ne doit pas fléchir de plus de 1 mm sous 170 kg de blocs répartis. Deux piquages tube Ø10 × 1 soudés en paroi arrière haute, aux deux extrémités, 200 mm droits, bouts lisses (raccord à compression). Deux pattes de levage démontables M8 sur le dessus.
3.2 Cadre avant (plat inox 60×10) — Soudé sur tout le pourtour de l'ouverture, angles à onglet ou à recouvrement, puis face avant dressée après soudage : planéité ≤ 0,3 mm/m (c'est la face d'appui du joint). Trous taraudés M4, axe à 15 mm du bord extérieur, pas 50, deux trous à 25 mm de chaque angle. Gorge de positionnement du toron : largeur 11, profondeur 2, axe à 40 mm du bord extérieur (au tiers de la largeur côté intérieur, à l'écart du chant de la vitre), continue, angles arrondis R10.
3.3 Couvercle : quatre longerons usinés (inox 316L, 60×24) — Profil : talon plein 28×24 en appui sur le cadre, battée 32×19 côté intérieur recevant la vitre (bande caoutchouc 1 mm + 13 mm + jeu), lèvre de 5 mm en façade. Perçages fraisés M4 en vis-à-vis des taraudages. Assemblage d'angle à proposer par l'atelier (onglet goujonné-collé, ou angles usinés dans la masse). Finition visible : brossé ou poli, à échantillonner.

3.4 Vitre et pose dans la battée — Verre feuilleté extra-clair 66.2 : deux verres de 6 mm à faible teneur en fer (type AGC Clearvision, Saint-Gobain Diamant, Pilkington Optiwhite) assemblés par deux PVB clairs, soit 13 mm. Couche antireflet déposée sur la face extérieure (face 1) — traitement magnétron durable type AGC Clearsight, Pilkington OptiView ou Glas Trösch Luxar Classic — pour que les gravures restent lisibles malgré le ciel de la mer du Nord ; pas de traitement sur la face intérieure, où les blocs viennent en appui direct. Bords polis. Pas de collage : la vitre est posée dans la battée sur une bande caoutchouc autocollante d'environ 1 mm, 30 mm de large, collée sur le fond de battée du longeron ; aucun contact verre/métal, la vitre reste démontable. La fourniture de la vitre peut être confiée à votre vitrier habituel ou au nôtre : indiquez-le dans votre réponse.
3.5 Joint et visserie — Toron EPDM plein Ø10 vulcanisé en cadre continu aux cotes de la gorge (+ 1 de rechange). Vis M4×30 fraisées Torx T20 inox A4, serrage en croix, environ 2 N·m ; le talon du longeron vient en butée sur le cadre à 5 mm au-dessus du fond de gorge : l'écrasement du joint est le même partout, quel que soit le zèle de celui qui visse.
3.6 Option : rampe LED en haut de la boîte — Un profilé LED étanche (IP67, 24 V, ~3 W, 3000 K, longueur ≈ 2 100 mm) fixé sous la paroi haute, à l'intérieur de la cavité, pour un éclairage rasant descendant sur les blocs. Nous fournissons le profilé ; nous vous demandons de chiffrer sa fixation (deux rails ou pattes soudées sous la paroi haute, 3 mm de réserve) et un troisième piquage Ø6 étanche en paroi arrière haute pour le passage du câble, avec presse-étoupe inox.
3.7 Niche dans la pierre — Le caisson est noyé dans le socle monobloc en pierre, sur tout son pourtour (dessous, dessus, dos, côtés). Devant le cadre, la pierre est dégagée d'une battée d'environ 64 mm de large sur 32 mm de profondeur qui reçoit le cadre et le longeron avec 4 mm de jeu ; la face de la pierre affleure ainsi la face du longeron et la vitre. Cette battée est taillée par l'atelier de pierre sur la base de vos cotes finales.

## 4. Dessins

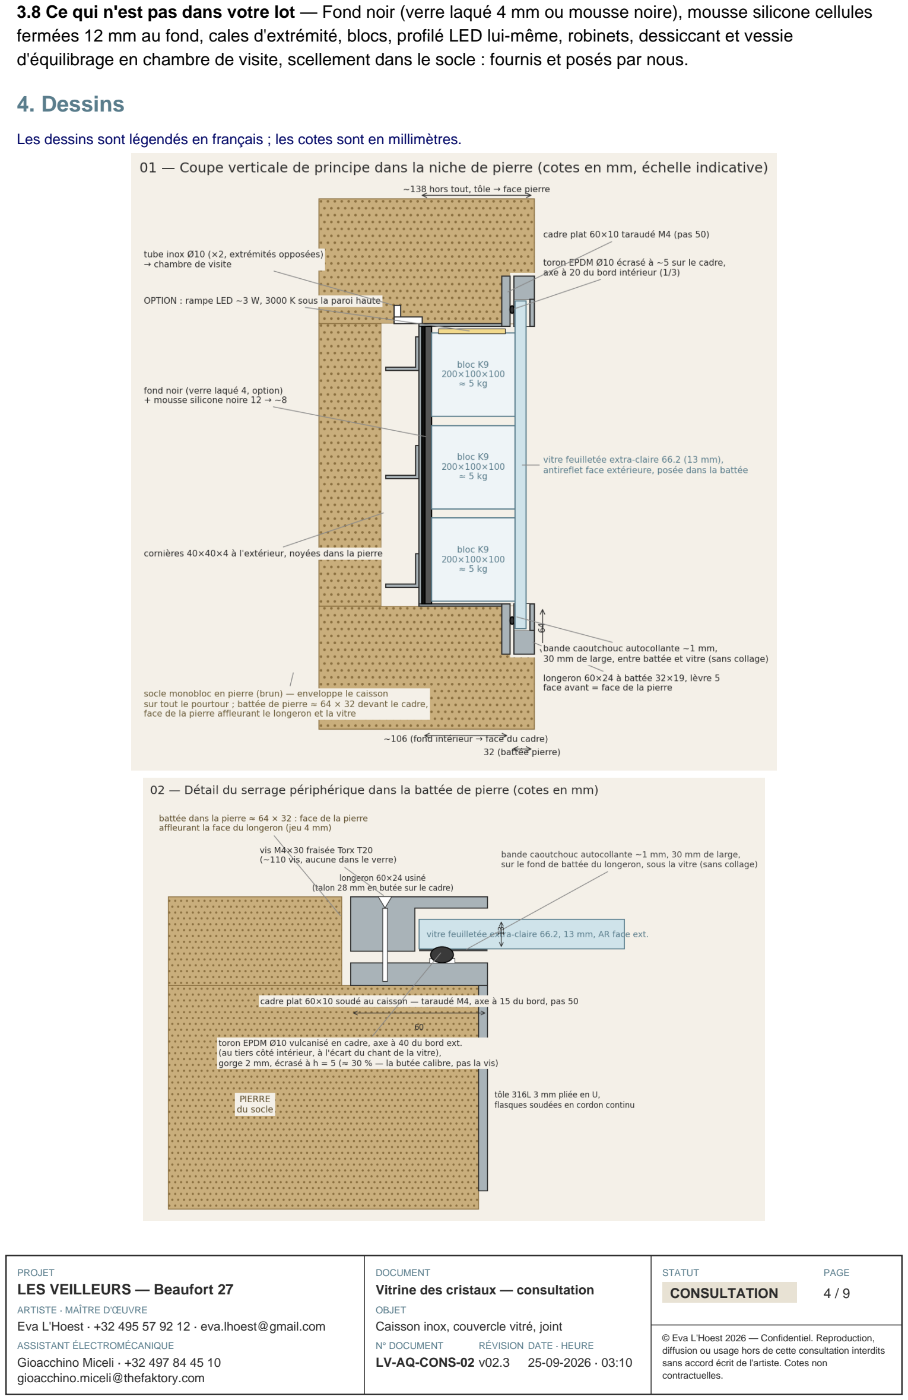
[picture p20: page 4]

PROJET
LES VEILLEURS — Beaufort 27

DOCUMENT
Vitrine des cristaux — consultation

STATUT
CONSULTATION

PAGE
4 / 9

3.8 Ce qui n'est pas dans votre lot — Fond noir (verre laqué 4 mm ou mousse noire), mousse silicone cellules fermées 12 mm au fond, cales d'extrémité, blocs, profilé LED lui-même, robinets, dessiccant et vessie d'équilibrage en chambre de visite, scellement dans le socle : fournis et posés par nous.

Les dessins sont légendés en français ; les cotes sont en millimètres.

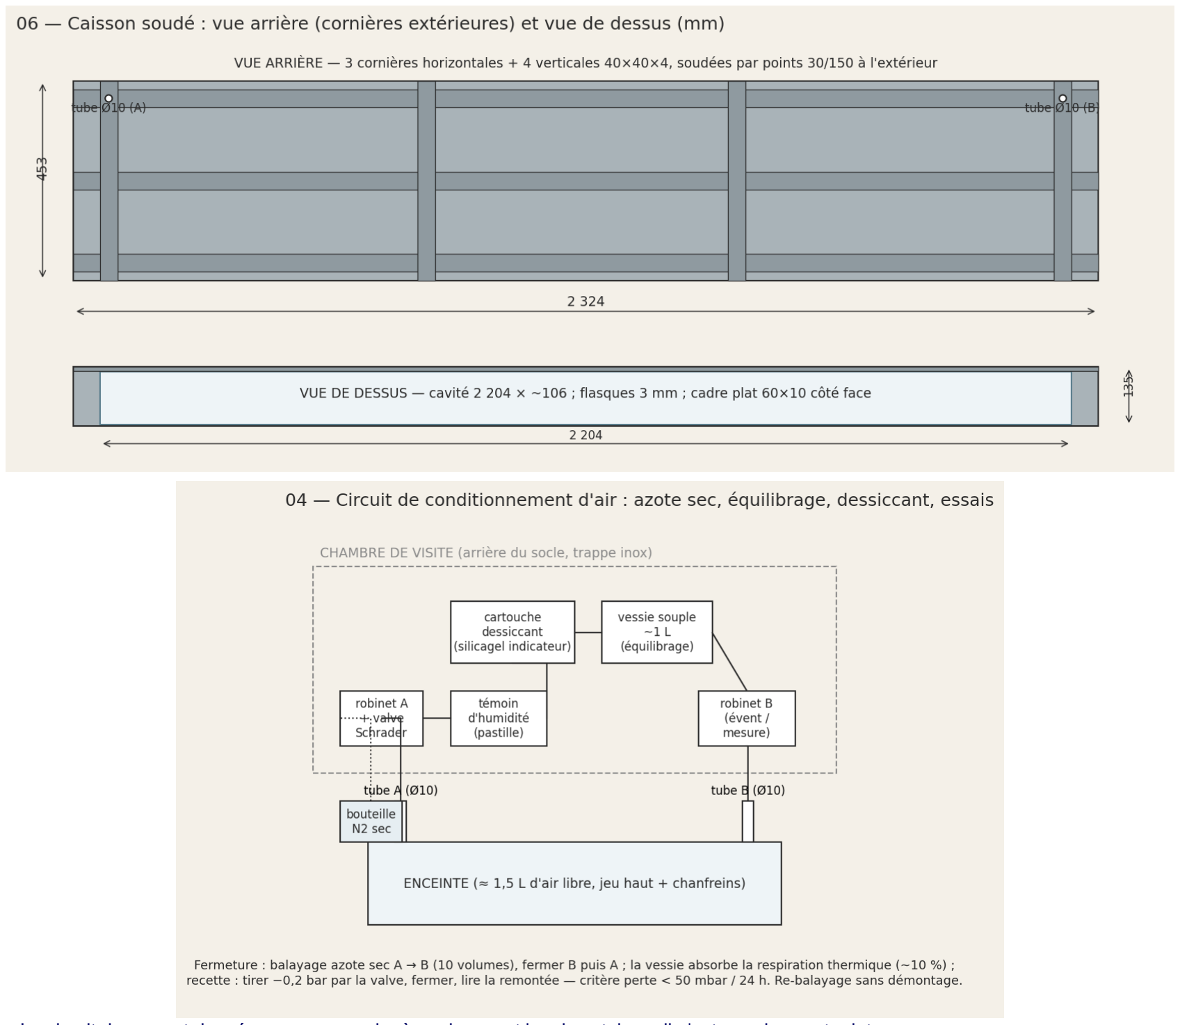
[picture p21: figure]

PROJET
LES VEILLEURS — Beaufort 27

DOCUMENT
Vitrine des cristaux — consultation

STATUT
CONSULTATION

PAGE
5 / 9

Le circuit de gaz est donné pour comprendre à quoi servent les deux tubes ; il n'est pas dans votre lot.

## 4 bis. Vues 3D éclatées

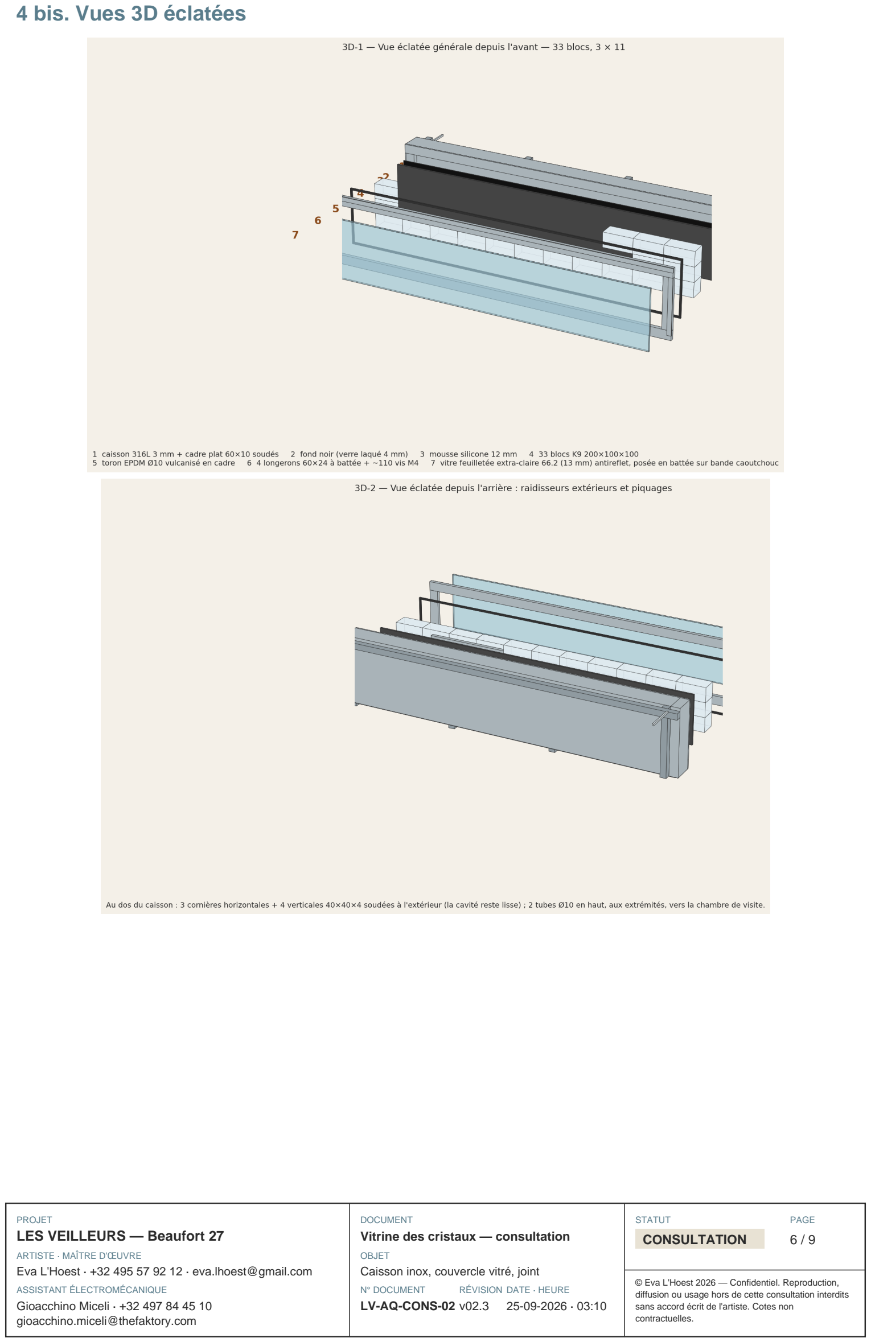
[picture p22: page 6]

PROJET
LES VEILLEURS — Beaufort 27

DOCUMENT
Vitrine des cristaux — consultation

STATUT
CONSULTATION

PAGE
6 / 9

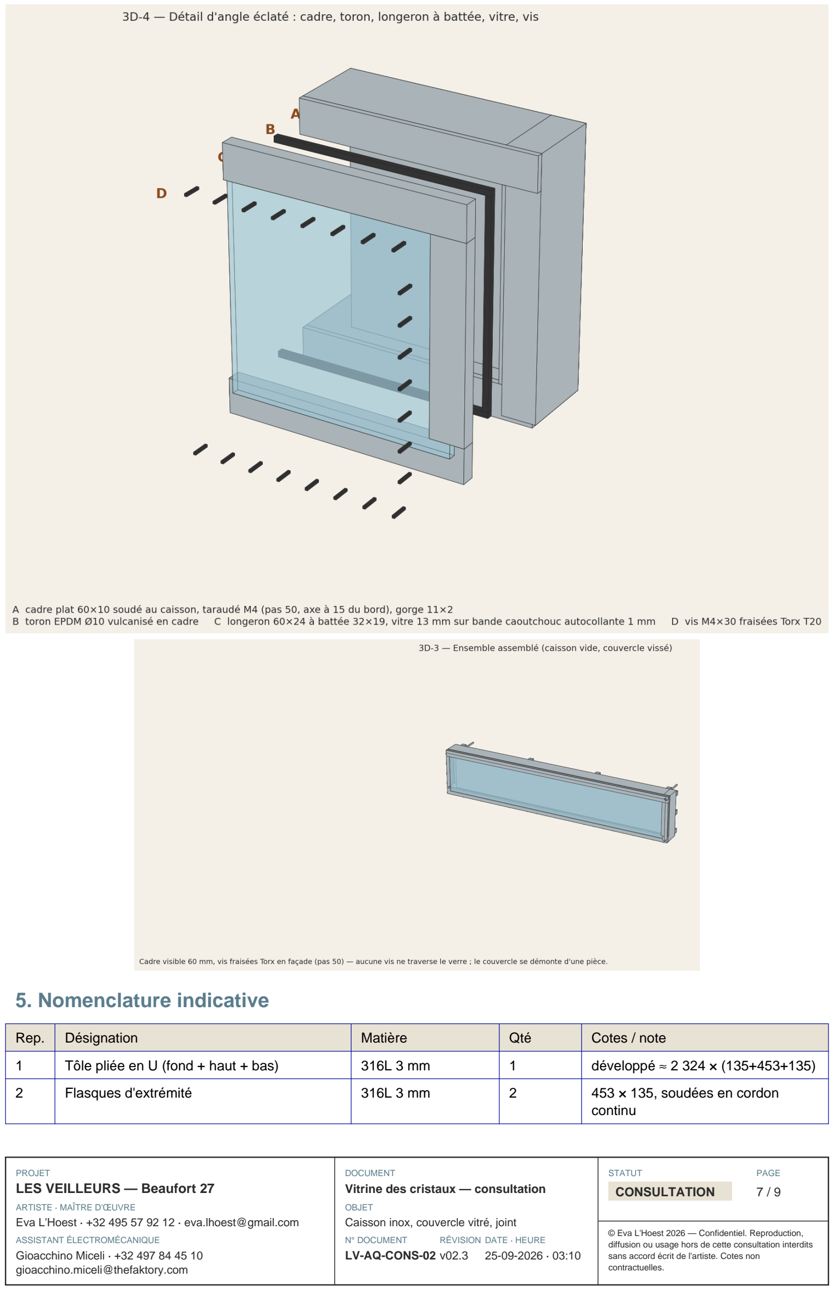
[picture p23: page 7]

PROJET
LES VEILLEURS — Beaufort 27

DOCUMENT
Vitrine des cristaux — consultation

STATUT
CONSULTATION

PAGE
7 / 9

## 5. Nomenclature indicative

Rep. | Désignation | Matière | Qté | Cotes / note
1 | Tôle pliée en U (fond + haut + bas) | 316L 3 mm | 1 | développé ≈ 2 324 × (135+453+135)
2 | Flasques d'extrémité | 316L 3 mm | 2 | 453 × 135, soudées en cordon continu

PROJET
LES VEILLEURS — Beaufort 27

DOCUMENT
Vitrine des cristaux — consultation

STATUT
CONSULTATION

PAGE
8 / 9
Rep. | Désignation | Matière | Qté | Cotes / note
3 | Cornières de raidissage extérieures | 316L 40×40×4 | 7 | 3 × 2 324 + 4 × 453
4 | Cadre avant plat | 316L 60×10 | ≈ 5,6 m | taraudé M4 pas 50, gorge 11×2, face dressée
5 | Longerons de serrage à battée | 316L 60×24 usiné | 4 | 2 × 2 324 + 2 × 453 (angles à définir)
6 | Vitre feuilletée extra-claire antireflet | 66.2 bas fer, AR face 1 | 1 | ≈ 2 264 × 393, bords polis
7 | Bande caoutchouc autocollante (EPDM ou silicone) 30 × 1 mm | caoutchouc | ≈ 6 m | sur le fond de battée du longeron
8 | Toron EPDM Ø10 vulcanisé en cadre | EPDM 70 Sh | 1 + 1 | périmètre ≈ 5,5 m
9 | Vis M4×30 fraisées Torx T20 | inox A4 | ≈ 115 | serrage en croix
10 | Piquages tube Ø10×1 | 316L | 2 | 200 mm, bouts lisses
11 | Pattes de levage démontables | inox M8 | 2 | sur le dessus
12 | Option LED : piquage Ø6 + presse-étoupe + fixations du profilé | 316L | 1 | profilé LED fourni par nous

## 6. Ce que nous vous demandons

Lot | Contenu | À chiffrer
A — Caisson | rep. 1 à 4, 10, 11 : pliage, soudure étanche, raidisseurs, cadre dressé, taraudages, gorge | prix ferme + délai
B — Couvercle | rep. 5 : 4 longerons usinés, assemblage d'angle, perçages, finition | prix ferme + délai
C — Vitrage | rep. 6 et 7 : vitre feuilletée extra-claire antireflet et bande caoutchouc (vitre par vous ou votre vitrier) | prix, ou « hors lot » si vous préférez que nous le fournissions
D — Joint et visserie | rep. 8 et 9 | prix
E — Essai à blanc | couvercle vissé sans blocs, mise en dépression −0,2 bar par les tubes, tenue 24 h (perte < 50 mbar) | prix, ou inclus
Option 1 | cadre visible réduit à 50 mm (plat 50×10 + longeron 50×24, battée 24) | plus-value / moins-value, faisabilité
Option 2 | finition visible des longerons : brossé / poli miroir | plus-value
Option 3 | rampe LED en haut de la boîte : fixations sous la paroi haute + piquage Ø6 étanche (rep. 12) | plus-value
Livraison | caisson vide et couvercle démonté, protégés, vers un atelier de taille de pierre (Belgique ou Suisse, à préciser) | prix transport ou départ atelier

## 7. Votre avis nous intéresse sur

- Le choix tôle 3 mm pliée + cornières extérieures : suffisant pour la planéité du fond, ou préférez-vous 4 mm ?
- Le dressage du cadre après soudage : usinage, ou rectification à la main suffit-elle pour ≤ 0,3 mm/m ?
- L'assemblage d'angle des longerons : onglet, angles usinés dans la masse, ou cadre soudé puis usiné d'une pièce ?
- Toron plein (30 %) ou tubulaire creux (50 %) : lequel tient le mieux dans le temps dehors ?
- Torx standard ou inviolable (TR) pour la visserie en façade ?
- Tout ce qui, selon vous, simplifie la fabrication sans changer l'apparence : cadre discret, aucune vis dans le verre, démontable.

## 8. Calendrier et suite

PROJET
LES VEILLEURS — Beaufort 27

DOCUMENT
Vitrine des cristaux — consultation

STATUT
CONSULTATION

PAGE
9 / 9
Étape | Délai
Votre avis constructif et votre estimation de prix | sous 3 semaines
Validation par l'artiste, puis plans d'exécution cotés (PDF + STEP/DXF) | 2 à 3 semaines
Prix ferme et commande | à réception des plans
Fabrication et essai à blanc en atelier | 4 à 6 semaines après commande
Livraison au socle (atelier principal) | à caler ensemble, hiver 2026-2027
Un échantillon de longeron avec toron, bande caoutchouc et morceau de vitre (200 mm) serait un bon premier pas : dites-nous si vous pouvez le faire et à quel prix.

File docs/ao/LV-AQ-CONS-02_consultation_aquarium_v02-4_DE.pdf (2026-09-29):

PROJEKT
LES VEILLEURS — Beaufort 27

KÜNSTLERIN · PROJEKTLEITUNG
Eva L'Hoest · +32 495 57 92 12 · eva.lhoest@gmail.com

ELEKTROMECHANISCHER ASSISTENT
Gioacchino Miceli · +32 497 84 45 10 gioacchino.miceli@thefaktory.com

DOKUMENT
Kristallvitrine — Anfrage

GEGENSTAND
Edelstahlkasten, Glasdeckel, Dichtung

DOKUMENT-NR.
LV-AQ-CONS-02

REVISION
v02.3

DATUM · UHRZEIT
25-09-2026 · 03:10

STATUS
ANFRAGE

SEITE
1 / 10

© Eva L'Hoest 2026 — Vertraulich. Vervielfältigung, Weitergabe oder Nutzung außerhalb dieser Anfrage ohne schriftliche Zustimmung der Künstlerin untersagt. Maße unverbindlich.

# Les Veilleurs — Kristallvitrine („Aquarium“)

Ausschreibungsunterlagen v02.3 · September 2026 · Edelstahlbau / Metallbau — Bitte um konstruktive Stellungnahme und Preisschätzung

## 1. Worum es geht

Ein dauerhaftes Kunstwerk an der belgischen Küste (Beaufort 27, Nordsee). In seinem Steinsockel zeigt eine Nische 33 lasergravierte optische Kristallblöcke auf schwarzem Grund hinter einer Glasscheibe, in einer trockenen Stickstoffatmosphäre, die sie vor der Meeresfeuchte schützt. Wir suchen eine Werkstatt für den Bau dieser Nische:
einen geschweißten, luftdichten Edelstahlkasten und seinen abnehmbaren verglasten Deckel. Es ist ein
handwerkliches Einzelstück, gebaut für mindestens zehn Jahre im Freien und um vor Ort geöffnet und gewartet zu werden. Die Maße unten sind unser Vorschlag; Ihre Meinung dazu, was einfacher, sicherer oder günstiger zu fertigen wäre, interessiert uns ebenso wie Ihr Preis.

## 2. Hauptmaße

Element | Maß / Wert | Anmerkung
Nutzbarer Innenraum L × H × T | 2 204 × 333 × ~106 mm | 11 Blöcke à 200 je Reihe + 4 mm Passstücke; 3 Reihen à 100 + 3 mm Spiel oben + 30 mm Reserve; Tiefe: schwarzer Grund 4 + verpresster Schaum 8 + Block 100 − die Blöcke berühren das Glas, 6 mm vor der Rahmenfläche
Kasten Außenmaß (Blech) | 2 324 × 453 × ~138 mm | = 60 mm Flachrahmen um den Innenraum; 138 = Blech → Vorderfläche der Leiste = Steinfläche
Nische im Steinsockel | Falz ≈ 64 × 32 rundum | der Kasten ist in den Stein eingebettet; der Falz nimmt Rahmen + Leiste auf (4 mm Spiel), die Steinfläche ist bündig mit dem Glas
Sichtbarer Rahmen an der Front | 60 mm | die Künstlerin wünscht ihn so unauffällig wie möglich: 50 mm willkommen, wenn der Falz es zulässt
Verbundglas eisenarm 66.2, entspiegelt | ≈ 2 264 × 393 × 13 mm — ≈ 29 kg | 2 × 6 mm eisenarm + PVB; Entspiegelungsschicht außen; polierte Kanten
K9-Kristallblöcke | 33 × (200 × 100 × 100) — ≈ 166 kg | von uns geliefert und vor Ort eingesetzt
Masse beladen | ≈ 350 kg | Kasten ≈ 60, Rahmen ≈ 26, Klemmleisten ≈ 63, Glas ≈ 29, Blöcke ≈ 166
Klemmschrauben | ≈ 110 × M4×30 Senkkopf Torx, Teilung 50 | keine Schraube durch das Glas
Dichtung | EPDM-Rundschnur Ø10, ~30 % verpresst in einer 2 mm Nut | der Anschlag der Leiste bestimmt die Verpressung, nicht das Anzugsmoment


PROJEKT
LES VEILLEURS — Beaufort 27

DOKUMENT
Kristallvitrine — Anfrage

STATUS
ANFRAGE

SEITE
2 / 10

PROJEKT


LES VEILLEURS — Beaufort 27

DOKUMENT
Kristallvitrine — Anfrage

STATUS
ANFRAGE

SEITE
3 / 10

## 3. Beschreibung Teil für Teil

3.1 Kasten (Edelstahl 316L, Blech 3 mm) — Blech U-förmig gekantet (Rückwand + obere und untere Wand), Innenradius ≤ 3 mm. Zwei Stirnbleche 3 mm mit durchgehender Naht geschweißt, Innennähte bündig geschliffen: der Innenraum muss glatt bleiben, die Blöcke gleiten an den Wänden. Aussteifungen nur außen: 3 waagrechte und 4 senkrechte Winkel 40×40×4, heftgeschweißt (30/150). Die Rückwand darf sich unter 170 kg verteilter Blöcke nicht mehr als 1 mm durchbiegen. Zwei Rohrstutzen Ø10 × 1 in die obere Rückwand geschweißt, an beiden Enden, 200 mm gerade, glatte Enden (Klemmverschraubung). Zwei abnehmbare Hebeösen M8 oben.
3.2 Frontrahmen (Edelstahl-Flachstahl 60×10) — Um die gesamte Öffnung geschweißt, Gehrungs- oder Überlappungsecken, danach Frontfläche nach dem Schweißen plangearbeitet: Ebenheit ≤ 0,3 mm/m (Auflagefläche der Dichtung). Gewindebohrungen M4, Achse 15 mm vom Außenrand, Teilung 50, zwei Bohrungen 25 mm von jeder Ecke. Positioniernut für die Rundschnur: Breite 11, Tiefe 2, Achse 40 mm vom Außenrand (im inneren Drittel der Breite, abseits der Glaskante), durchgehend, Ecken R10.
3.3 Deckel: vier gefräste Klemmleisten (Edelstahl 316L, 60×24) — Profil: voller Absatz 28×24 als Auflage auf dem Rahmen, Falz 32×19 innen für das Glas (Gummiband 1 mm + 13 mm + Spiel), 5 mm Lippe an der Front. Senkbohrungen M4 gegenüber den Gewindebohrungen. Eckverbindung von der Werkstatt vorzuschlagen (gedübelte und geklebte Gehrung oder aus dem Vollen gefräste Ecken). Sichtbare Oberfläche: gebürstet oder poliert, Muster abzustimmen.

3.4 Glas und Einlegen in den Falz — Verbundglas eisenarm 66.2: zwei 6 mm eisenarme Scheiben (Typ AGC Clearvision, Saint-Gobain Diamant, Pilkington Optiwhite) mit zwei klaren PVB-Folien, also 13 mm. Entspiegelungsschicht auf der Außenseite (Seite 1) — dauerhafte Magnetron-Beschichtung wie AGC Clearsight, Pilkington OptiView oder Glas Trösch Luxar Classic — damit die Gravuren unter dem Nordseehimmel lesbar bleiben; keine Beschichtung innen, wo die Blöcke direkt anliegen. Polierte Kanten. Keine Verklebung: das Glas liegt im Falz auf einem selbstklebenden Gummiband von etwa 1 mm Dicke und 30 mm Breite, auf den Falzgrund der Leiste geklebt; kein Glas-Metall-Kontakt, das Glas bleibt demontierbar. Das Glas kann von Ihrem Glaser oder von unserem kommen: bitte in Ihrer Antwort angeben.
3.5 Dichtung und Schrauben — Volle EPDM-Rundschnur Ø10, zu einem durchgehenden Rahmen nach Nutmaß vulkanisiert (+ 1 Ersatz). Schrauben M4×30 Senkkopf Torx T20 Edelstahl A4, über Kreuz angezogen, etwa 2 N·m; der Absatz der Leiste setzt 5 mm über dem Nutgrund auf dem Rahmen auf: die Verpressung der Dichtung ist überall gleich, unabhängig vom Eifer des Schraubenden.
3.6 Option: LED-Leiste oben im Kasten — Ein dichtes LED-Profil (IP67, 24 V, ~3 W, 3000 K, Länge ≈ 2 100 mm) unter der oberen Wand, im Innenraum, für nach unten streifendes Licht auf die Blöcke. Wir liefern das Profil; wir bitten Sie, die Befestigung zu kalkulieren (zwei Schienen oder Laschen unter der oberen Wand geschweißt, 3 mm Reserve) sowie einen dritten dichten Stutzen Ø6 in der oberen Rückwand für das Kabel, mit Edelstahl-Kabelverschraubung.
3.7 Nische im Stein — Der Kasten ist rundum in den monolithischen Steinsockel eingebettet (unten, oben, hinten, seitlich). Vor dem Rahmen ist der Stein mit einem Falz von etwa 64 mm Breite und 32 mm Tiefe ausgespart, der Rahmen und Leiste mit 4 mm Spiel aufnimmt, sodass die Steinfläche bündig mit der Leistenfläche und dem Glas

PROJEKT

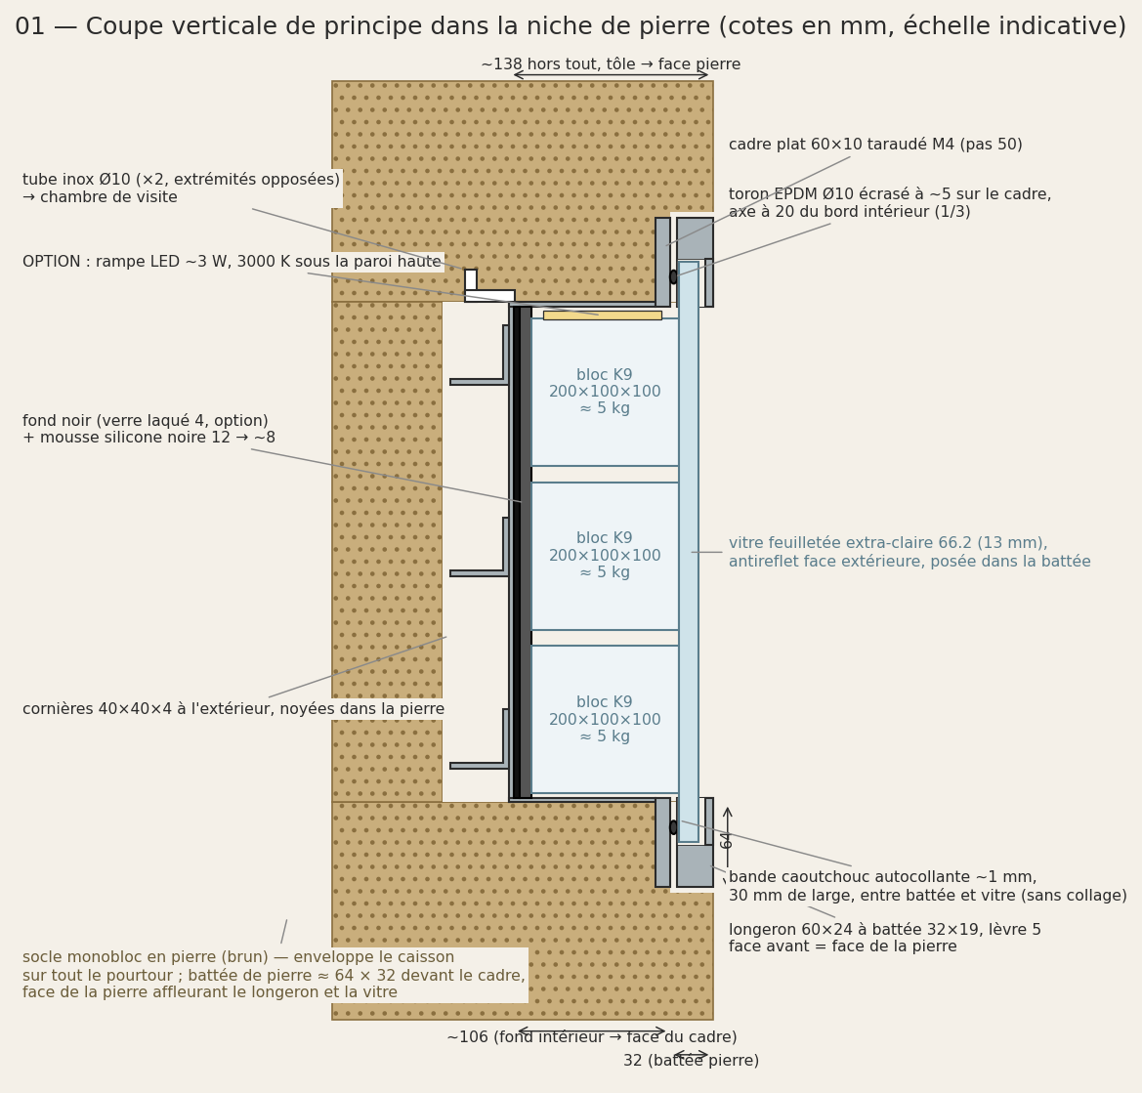
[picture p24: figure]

LES VEILLEURS — Beaufort 27

DOKUMENT
Kristallvitrine — Anfrage

STATUS
ANFRAGE

SEITE
4 / 10

liegt. Dieser Falz wird von der Steinmetzwerkstatt nach Ihren endgültigen Maßen gefertigt.
3.8 Nicht in Ihrem Los — Schwarzer Hintergrund (lackiertes Glas 4 mm oder schwarzer Schaum), geschlossenzelliger Silikonschaum 12 mm hinten, Endpassstücke, Blöcke, das LED-Profil selbst, Ventile, Trockenmittel und Druckausgleichsblase in der Wartungskammer, Einbetten in den Sockel: von uns geliefert und montiert.

## 4. Zeichnungen

Die Zeichnungen sind auf Französisch beschriftet; Maße in Millimetern.

PROJEKT

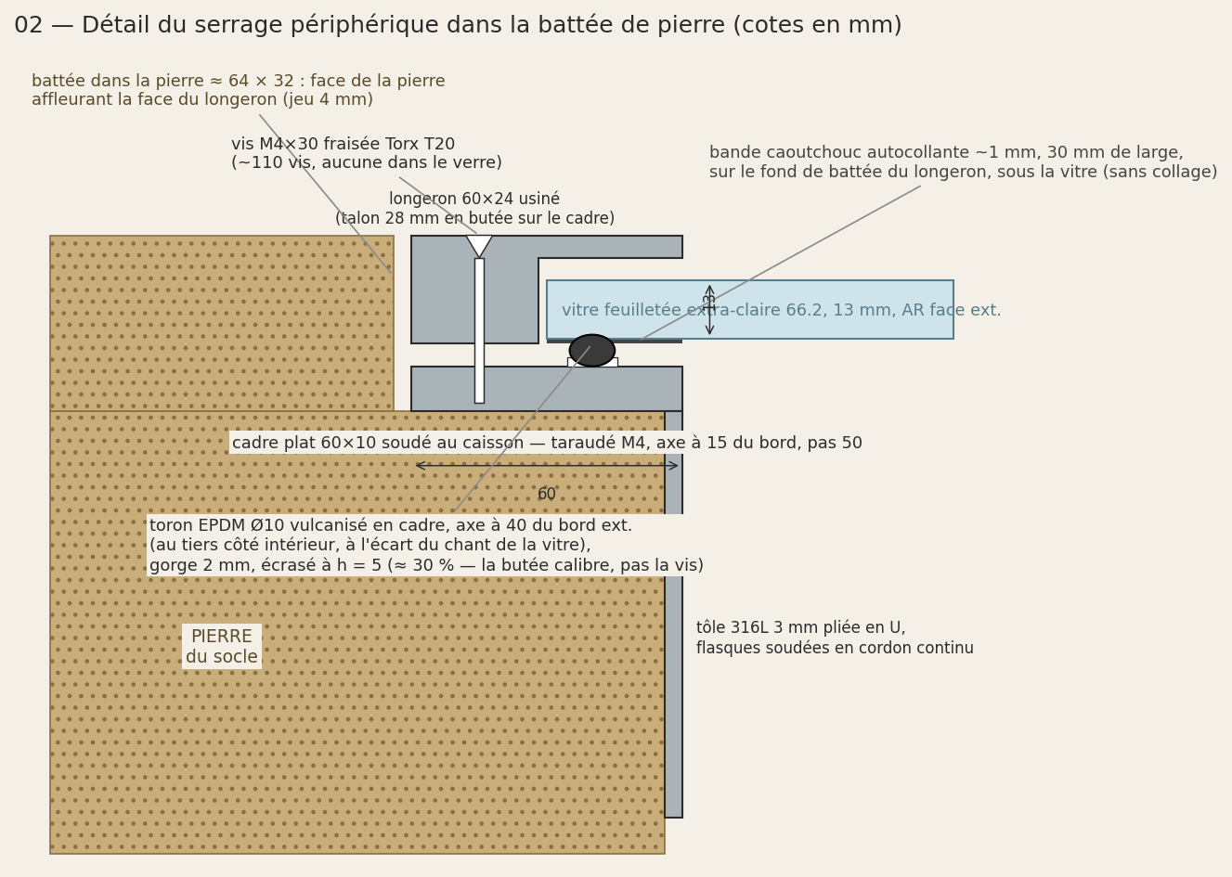
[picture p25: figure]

LES VEILLEURS — Beaufort 27

DOKUMENT
Kristallvitrine — Anfrage

STATUS
ANFRAGE

SEITE
5 / 10


PROJEKT
LES VEILLEURS — Beaufort 27

DOKUMENT
Kristallvitrine — Anfrage

STATUS
ANFRAGE

SEITE
6 / 10

Der Gaskreislauf ist dargestellt, um den Zweck der beiden Rohre zu erklären; er gehört nicht zu Ihrem Los.

## 4 bis. Explosionsansichten 3D


PROJEKT
LES VEILLEURS — Beaufort 27

DOKUMENT
Kristallvitrine — Anfrage

STATUS
ANFRAGE

SEITE
7 / 10


PROJEKT
LES VEILLEURS — Beaufort 27

DOKUMENT
Kristallvitrine — Anfrage

STATUS
ANFRAGE

SEITE
8 / 10

## 5. Stückliste (Richtwerte)

Pos. | Bezeichnung | Werkstoff | Menge | Maße / Anmerkung
1 | U-gekantetes Blech (Rückwand + oben + unten) | 316L 3 mm | 1 | Abwicklung ≈ 2 324 × (135+453+135)
2 | Stirnbleche | 316L 3 mm | 2 | 453 × 135, durchgehende Naht

PROJEKT
LES VEILLEURS — Beaufort 27

DOKUMENT
Kristallvitrine — Anfrage

STATUS
ANFRAGE

SEITE
9 / 10
Pos. | Bezeichnung | Werkstoff | Menge | Maße / Anmerkung
3 | Äußere Aussteifungswinkel | 316L 40×40×4 | 7 | 3 × 2 324 + 4 × 453
4 | Flacher Frontrahmen | 316L 60×10 | ≈ 5,6 m | Gewinde M4 Teilung 50, Nut 11×2, plangearbeitet
5 | Klemmleisten mit Falz | 316L 60×24 gefräst | 4 | 2 × 2 324 + 2 × 453 (Ecken festzulegen)
6 | Verbundglas eisenarm entspiegelt | 66.2 eisenarm, AR Seite 1 | 1 | ≈ 2 264 × 393, polierte Kanten
7 | Selbstklebendes Gummiband (EPDM oder Silikon) 30 × 1 mm | Gummi | ≈ 6 m | auf dem Falzgrund der Leiste
8 | EPDM-Rundschnur Ø10 vulkanisierter Rahmen | EPDM 70 Sh | 1 + 1 | Umfang ≈ 5,5 m
9 | Schrauben M4×30 Senkkopf Torx T20 | Edelstahl A4 | ≈ 115 | über Kreuz anziehen
10 | Rohrstutzen Ø10×1 | 316L | 2 | 200 mm, glatte Enden
11 | Abnehmbare Hebeösen | Edelstahl M8 | 2 | oben
12 | LED-Option: Stutzen Ø6 + Verschraubung + Profilbefestigung | 316L | 1 | LED-Profil von uns geliefert

## 6. Was wir von Ihnen erbitten

Los | Inhalt | Zu kalkulieren
A — Kasten | Pos. 1 bis 4, 10, 11: Kanten, dichtes Schweißen, Aussteifungen, plangearbeiteter Rahmen, Gewinde, Nut | Festpreis + Lieferzeit
B — Deckel | Pos. 5: 4 gefräste Leisten, Eckverbindung, Bohrungen, Oberfläche | Festpreis + Lieferzeit
C — Verglasung | Pos. 6 und 7: Verbundglas eisenarm entspiegelt und Gummiband (Glas durch Sie oder Ihren Glaser) | Preis, oder „nicht enthalten“, falls wir es liefern sollen
D — Dichtung und Schrauben | Pos. 8 und 9 | Preis
E — Trockenprüfung | Deckel ohne Blöcke verschraubt, −0,2 bar über die Rohre, 24 h halten (Verlust < 50 mbar) | Preis, oder enthalten
Option 1 | sichtbarer Rahmen auf 50 mm reduziert (Flach 50×10 + Leiste 50×24, Falz 24) | Mehr-/Minderpreis, Machbarkeit
Option 2 | sichtbare Oberfläche der Leisten: gebürstet / spiegelpoliert | Mehrpreis
Option 3 | LED-Leiste oben im Kasten: Befestigung unter der oberen Wand + dichter Stutzen Ø6 (Pos. 12) | Mehrpreis
Lieferung | leerer Kasten und demontierter Deckel, geschützt, an eine Steinmetzwerkstatt (Belgien oder Schweiz, noch festzulegen) | Transportpreis oder ab Werk

## 7. Ihre Meinung interessiert uns zu

- Gekantetes Blech 3 mm + äußere Winkel: ausreichend für die Ebenheit der Rückwand, oder bevorzugen Sie 4 mm?
- Planarbeiten des Rahmens nach dem Schweißen: Fräsen, oder genügt Richten von Hand für ≤ 0,3 mm/m?
- Eckverbindung der Leisten: Gehrung, aus dem Vollen gefräste Ecken, oder geschweißter Rahmen in einem Stück bearbeitet?
- Volle Schnur (30 %) oder Hohlschnur (50 %): was hält im Freien länger?
- Standard- oder manipulationssicherer (TR) Torx für die Frontschrauben?
- Alles, was aus Ihrer Sicht die Fertigung vereinfacht, ohne das Aussehen zu ändern: unauffälliger Rahmen, keine Schraube im Glas, demontierbar.

PROJEKT
LES VEILLEURS — Beaufort 27

DOKUMENT
Kristallvitrine — Anfrage

STATUS
ANFRAGE

SEITE
10 / 10

## 8. Zeitplan und weiteres Vorgehen

Schritt | Frist
Ihre konstruktive Stellungnahme und Preisschätzung | innerhalb von 3 Wochen
Freigabe durch die Künstlerin, danach bemaßte Ausführungszeichnungen (PDF + STEP/DXF) | 2 bis 3 Wochen
Festpreis und Bestellung | nach Erhalt der Zeichnungen
Fertigung und Trockenprüfung in der Werkstatt | 4 bis 6 Wochen nach Bestellung
Lieferung an den Sockel (Hauptwerkstatt) | gemeinsam abzustimmen, Winter 2026-2027

Ein 200 mm Muster einer Klemmleiste mit Schnur, Gummiband und einem Stück Glas wäre ein guter erster Schritt: sagen Sie uns, ob Sie es fertigen können und zu welchem Preis.

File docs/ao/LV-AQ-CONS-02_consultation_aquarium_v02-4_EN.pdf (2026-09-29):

PROJECT
LES VEILLEURS — Beaufort 27

ARTIST · PROJECT LEAD
Eva L'Hoest · +32 495 57 92 12 · eva.lhoest@gmail.com

ELECTROMECHANICAL ASSISTANT
Gioacchino Miceli · +32 497 84 45 10 gioacchino.miceli@thefaktory.com

DOCUMENT
Crystal showcase — tender

SUBJECT
Stainless box, glazed cover, seal

DOCUMENT No.
LV-AQ-CONS-02

REVISION
v02.3

DATE · TIME
25-09-2026 · 03:10

STATUS
FOR TENDER

PAGE
1 / 9

© Eva L'Hoest 2026 — Confidential. No reproduction, distribution or use outside this tender without the artist's written consent. Dimensions not contractual.

# Les Veilleurs — Crystal showcase (“aquarium”)

Tender documentation v02.3 · September 2026 · stainless-steel fabrication / metal joinery — request for constructive advice and price estimate

## 1. What this is

A permanent artwork on the Belgian coast (Beaufort 27, North Sea). Set into its stone base, a niche displays 33 laser-engraved optical crystal blocks on a black background behind a glass pane, in a dry-nitrogen atmosphere
that protects them from sea humidity. We are looking for a workshop to build this niche: a welded, airtight stainless-steel box and its removable glazed cover. A one-off, hand-built piece meant to last at least ten years outdoors and to be opened and serviced on site. The dimensions below are our proposal; your view on what would be
simpler, safer or cheaper to make interests us as much as your price.

## 2. Main dimensions

Item | Dimension / value | Note
Usable inner cavity L × H × D | 2,204 × 333 × ~106 mm | 11 blocks of 200 per row + 4 mm shims; 3 rows of 100 + 3 mm top clearance + 30 mm reserve; depth: black background 4 + compressed foam 8 + block 100 − the blocks touch the glass, 6 mm in front of the frame face
Box overall (sheet) | 2,324 × 453 × ~138 mm | = 60 mm flat frame around the cavity; 138 = sheet → front face of the bar = stone face
Niche in the stone base | rebate ≈ 64 × 32 all around | the box is embedded in the stone; the rebate takes frame + bar (4 mm clearance), the stone face is flush with the glass
Visible frame on the front | 60 mm | the artist wants it as discreet as possible: 50 mm welcome if the rebate allows
Laminated low-iron glass 66.2, anti-reflective | ≈ 2,264 × 393 × 13 mm — ≈ 29 kg | 2 × 6 mm low-iron + PVB; anti-reflective coating on the outer face; polished edges
K9 crystal blocks | 33 × (200 × 100 × 100) — ≈ 166 kg | supplied and installed by us, on site
Loaded mass | ≈ 350 kg | box ≈ 60, frame ≈ 26, clamping bars ≈ 63, glass ≈ 29, blocks ≈ 166
Clamping screws | ≈ 110 × M4×30 countersunk Torx, 50 mm pitch | no screw passes through the glass
Sealing | EPDM cord Ø10 compressed ~30 % in a 2 mm groove | the bar's shoulder sets the compression, not the screw torque


PROJECT
LES VEILLEURS — Beaufort 27

DOCUMENT
Crystal showcase — tender

STATUS
FOR TENDER

PAGE
2 / 9

PROJECT


LES VEILLEURS — Beaufort 27

DOCUMENT
Crystal showcase — tender

STATUS
FOR TENDER

PAGE
3 / 9

## 3. Part-by-part description

3.1 Box (316L stainless, 3 mm sheet) — Sheet bent into a U (back + top and bottom walls), inner radius ≤ 3 mm. Two 3 mm end plates welded with a continuous seam, inner seams ground flush: the cavity must stay smooth, the blocks slide against the walls. Stiffeners on the outside only: 3 horizontal and 4 vertical 40×40×4 angles, stitch-welded (30/150). The back must not deflect more than 1 mm under 170 kg of distributed blocks. Two Ø10 × 1 tube stubs welded into the upper back wall at both ends, 200 mm straight, plain ends (compression fitting). Two removable M8 lifting lugs on top.
3.2 Front frame (60×10 stainless flat bar) — Welded all around the opening, mitred or lapped corners, then the front face dressed after welding: flatness ≤ 0.3 mm/m (this is the seal's bearing face). M4 tapped holes, axis 15 mm from the outer edge, 50 mm pitch, two holes 25 mm from each corner. Cord locating groove: 11 wide, 2 deep, axis 40 mm from the outer edge (one third of the width from the inner edge, away from the glass edge), continuous, R10 rounded corners.
3.3 Cover: four machined clamping bars (316L stainless, 60×24) — Profile: solid 28×24 shoulder bearing on the frame, 32×19 rebate on the inner side receiving the glass (1 mm rubber strip + 13 mm + clearance), 5 mm lip on the front. Countersunk M4 holes matching the tapped holes. Corner joint to be proposed by the workshop (dowelled-and-bonded mitre, or corners machined from solid). Visible finish: brushed or polished, sample to be agreed.

3.4 Glass and seating in the rebate — Laminated low-iron glass 66.2: two 6 mm low-iron panes (e.g. AGC Clearvision, Saint-Gobain Diamant, Pilkington Optiwhite) laminated with two clear PVB layers, i.e. 13 mm. Anti-reflective coating on the outer face (face 1) — durable magnetron coating such as AGC Clearsight, Pilkington OptiView or Glas Trösch Luxar Classic — so the engravings stay legible under the North Sea sky; no coating on the inner face, where the blocks bear directly. Polished edges. No bonding: the glass sits in the rebate on a self-adhesive rubber strip about 1 mm thick and 30 mm wide, stuck to the rebate floor of the bar; no glass-to-metal contact, the glass stays removable. The glass may come from your usual glazier or from ours: please say which in your reply.
3.5 Seal and screws — Solid EPDM cord Ø10 vulcanised into a continuous frame to the groove dimensions (+ 1 spare). M4×30 countersunk Torx T20 A4 stainless screws, tightened crosswise, about 2 N·m; the bar's shoulder bottoms on the frame 5 mm above the groove floor, so seal compression is the same everywhere whatever the enthusiasm of the person tightening.
3.6 Option: LED strip at the top of the box — A sealed LED profile (IP67, 24 V, ~3 W, 3000 K, length ≈ 2,100 mm) fixed under the top wall, inside the cavity, for downward grazing light on the blocks. We supply the profile; we ask you to price its fixing (two rails or lugs welded under the top wall, 3 mm reserve) and a third sealed Ø6 stub in the upper back wall for the cable, with stainless cable gland.
3.7 Niche in the stone — The box is embedded in the monolithic stone base all around (bottom, top, back, sides). In front of the frame the stone is cut back by a rebate about 64 mm wide and 32 mm deep that takes the frame and the bar with 4 mm clearance, so the stone face is flush with the bar face and the glass. This rebate is cut by the stone workshop from your final dimensions.

## 4. Drawings


PROJECT
LES VEILLEURS — Beaufort 27

DOCUMENT
Crystal showcase — tender

STATUS
FOR TENDER

PAGE
4 / 9

3.8 Not in your scope — Black background (4 mm lacquered glass or black foam), 12 mm closed-cell silicone foam at the back, end shims, blocks, the LED profile itself, valves, desiccant and pressure-balancing bladder in the service chamber, grouting into the base: supplied and installed by us.

Drawings are labelled in French; dimensions are in millimetres.


PROJECT
LES VEILLEURS — Beaufort 27

DOCUMENT
Crystal showcase — tender

STATUS
FOR TENDER

PAGE
5 / 9

The gas circuit is shown to explain what the two tubes are for; it is not in your scope.

## 4 bis. Exploded 3D views


PROJECT
LES VEILLEURS — Beaufort 27

DOCUMENT
Crystal showcase — tender

STATUS
FOR TENDER

PAGE
6 / 9


PROJECT
LES VEILLEURS — Beaufort 27

DOCUMENT
Crystal showcase — tender

STATUS
FOR TENDER

PAGE
7 / 9

## 5. Indicative bill of materials

Ref. | Description | Material | Qty | Dimensions / note
1 | U-bent sheet (back + top + bottom) | 316L 3 mm | 1 | blank ≈ 2,324 × (135+453+135)
2 | End plates | 316L 3 mm | 2 | 453 × 135, continuous seam

PROJECT
LES VEILLEURS — Beaufort 27

DOCUMENT
Crystal showcase — tender

STATUS
FOR TENDER

PAGE
8 / 9
Ref. | Description | Material | Qty | Dimensions / note
3 | External stiffening angles | 316L 40×40×4 | 7 | 3 × 2,324 + 4 × 453
4 | Front flat frame | 316L 60×10 | ≈ 5.6 m | M4 tapped 50 pitch, 11×2 groove, face dressed
5 | Rebated clamping bars | 316L 60×24 machined | 4 | 2 × 2,324 + 2 × 453 (corners to define)
6 | Laminated low-iron AR glass | 66.2 low-iron, AR face 1 | 1 | ≈ 2,264 × 393, polished edges
7 | Self-adhesive rubber strip (EPDM or silicone) 30 × 1 mm | rubber | ≈ 6 m | on the rebate floor of the bar
8 | EPDM cord Ø10 vulcanised frame | EPDM 70 Sh | 1 + 1 | perimeter ≈ 5.5 m
9 | M4×30 countersunk Torx T20 screws | A4 stainless | ≈ 115 | crosswise tightening
10 | Ø10×1 tube stubs | 316L | 2 | 200 mm, plain ends
11 | Removable lifting lugs | stainless M8 | 2 | on top
12 | LED option: Ø6 stub + gland + profile fixings | 316L | 1 | LED profile supplied by us

## 6. What we ask of you

Package | Content | To price
A — Box | refs 1 to 4, 10, 11: bending, airtight welding, stiffeners, dressed frame, tapping, groove | firm price + lead time
B — Cover | ref. 5: 4 machined bars, corner joint, holes, finish | firm price + lead time
C — Glazing | refs 6 and 7: laminated low-iron AR glass and rubber strip (glass by you or your glazier) | price, or “excluded” if you prefer we supply it
D — Seal and screws | refs 8 and 9 | price
E — Dry test | cover screwed on without blocks, −0.2 bar through the tubes, 24 h hold (loss < 50 mbar) | price, or included
Option 1 | visible frame reduced to 50 mm (50×10 flat + 50×24 bar, 24 rebate) | extra / saving, feasibility
Option 2 | visible finish of the bars: brushed / mirror polished | extra
Option 3 | LED strip at the top of the box: fixings under the top wall + sealed Ø6 stub (ref. 12) | extra
Delivery | empty box and dismounted cover, protected, to a stone workshop (Belgium or Switzerland, to be confirmed) | transport price or ex works

## 7. We would value your view on

- 3 mm bent sheet + external angles: enough for back flatness, or would you prefer 4 mm?
- Dressing the frame after welding: machining, or is hand rectification enough for ≤ 0.3 mm/m?
- Corner joint of the bars: mitre, corners machined from solid, or a welded frame machined as one piece?
- Solid cord (30 %) or hollow tubular cord (50 %): which lasts better outdoors?
- Standard or tamper-resistant (TR) Torx for the front screws?
- Anything that, in your view, simplifies fabrication without changing the look: discreet frame, no screw in the glass, demountable.

## 8. Schedule and next steps

Step | Timing
Your constructive advice and price estimate | within 3 weeks

PROJECT
LES VEILLEURS — Beaufort 27

DOCUMENT
Crystal showcase — tender

STATUS
FOR TENDER

PAGE
9 / 9
Step | Timing
Artist's approval, then dimensioned execution drawings (PDF + STEP/DXF) | 2 to 3 weeks
Firm price and order | on receipt of the drawings
Fabrication and dry test in the workshop | 4 to 6 weeks after order
Delivery to the base (main workshop) | to be agreed together, winter 2026-2027
A 200 mm sample of clamping bar with cord, rubber strip and a piece of glass would be a good first step: tell us if you can make it and at what price.

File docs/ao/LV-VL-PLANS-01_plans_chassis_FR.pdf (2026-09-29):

# Les Veilleurs — Châssis de l'écran — Plans (LV-VL-PLANS-01, rév. 1, 29-09-2026)

# Recueil des planches du lot châssis · schémas légendés en français

1. LV-VL-CH-02 | Châssis v02 tube 80×40×3 316L — élévation, vue latérale, section, nomenclature
2. LV-VL-CAO-00 | STEP « ecran v00 » (J. Miceli) — trois vues (profil 100×40, ramené à 80×40×3)
3. LV-VL-FIG-01 | Élévation de principe, cotes en mm
4. LV-VL-FIG-03 | Le sandwich verre / lenticulaire / verre (lot vitrage, pour information)
5. LV-VL-FIG-04 | Circuit d'air sec, poche d'équilibrage et dessiccant (pour information)
6. LV-VL-FIG-05 | Séquence de montage

Profil arrêté le 29-09-2026 : tube rectangulaire 80 × 40 × 3 mm inox 316L (les planches antérieures en U 80×40×5 et en tube 100×40 sont retirées). Planches établies avec l'aide de l'IA, sous le contrôle de l'équipe — sous réserve du plan de réalisation de l'atelier. Cotes non contractuelles.

© Eva L'Hoest 2026 — Confidentiel / Confidential. Cotes non contractuelles / Dimensions not contractual.

# Les Veilleurs — Vitrine lenticulaire — Châssis v02 tube 80×40×3 316L

## LV-VL-CH-02 · rév. 2 · 29-09-2026 · CONSULTATION · schéma légendé en français

PROJET


## LES VEILLEURS — Beaufort 27

ARTISTE · MAÎTRE D'ŒUVRE

## Eva L'Hoest · +32 495 57 92 12 · eva.lhoest@gmail.com

ASSISTANT ÉLECTROMÉCANIQUE

## Gioacchino Miceli · +32 497 84 45 10 · gioacchino.miceli@thefaktory.com

DOCUMENT

## Vitrine lenticulaire — Châssis v02 tube 80×40×3 316L

OBJET

## Châssis de l'écran : profil arrêté 80×40×3, géométrie selon STEP ecran v00 (J. Miceli)

N° DOCUMENT · RÉVISION · DATE · HEURE

## LV-VL-CH-02 · rév. 2 · 29-09-2026

EN LIGNE

### https://vitrine-lenticulaire.vercel.app

STATUT

## CONSULTATION

© Eva L'Hoest 2026 — Confidentiel. Reproduction, diffusion ou usage hors de cette consultation interdits sans accord écrit de l'artiste. Cotes non contractuelles.

Les Veilleurs — La vitrine lenticulaire — STEP « ecran v00 100x40x3 » (J. Miceli) — trois vues

## LV-VL-CAO-00 · rév. 0 · 24-09-26 · ÉTUDE · schéma légendé en français

PROJET


## LES VEILLEURS — Beaufort 27

ARTISTE · MAÎTRE D'ŒUVRE

## Eva L'Hoest · +32 495 57 92 12 · eva.lhoest@gmail.com

ASSISTANT ÉLECTROMÉCANIQUE

## Gioacchino Miceli · +32 497 84 45 10 · gioacchino.miceli@thefaktory.com

DOCUMENT

## La vitrine lenticulaire — STEP « ecran v00 100x40x3 » (J. Miceli) — trois vues

OBJET

## Double vitrage démontable, lenticulaire libre, châssis U inox

N° DOCUMENT · RÉVISION · DATE · HEURE

## LV-VL-CAO-00 · rév. 0 · 24-09-26

STATUT

## ÉTUDE

© Eva L'Hoest 2026 — Confidentiel. Reproduction, diffusion ou usage hors de cette consultation interdits sans accord écrit de l'artiste. Cotes non contractuelles.

# Les Veilleurs — La vitrine lenticulaire — Élévation, cotes en mm

## LV-VL-FIG-01 · rév. 1 · 24-09-26 · ESQUISSE · schéma légendé en français


PROJET

## LES VEILLEURS — Beaufort 27

ARTISTE · MAÎTRE D'ŒUVRE

## Eva L'Hoest · +32 495 57 92 12 · eva.lhoest@gmail.com

ASSISTANT ÉLECTROMÉCANIQUE

## Gioacchino Miceli · +32 497 84 45 10 · gioacchino.miceli@thefaktory.com

DOCUMENT

## La vitrine lenticulaire — Élévation, cotes en mm

OBJET

## Double vitrage démontable, lenticulaire libre, châssis U inox

N° DOCUMENT · RÉVISION · DATE · HEURE

## LV-VL-FIG-01 · rév. 1 · 24-09-26

STATUT

## ESQUISSE

© Eva L'Hoest 2026 — Confidentiel. Reproduction, diffusion ou usage hors de cette consultation interdits sans accord écrit de l'artiste. Cotes non contractuelles.

# Les Veilleurs — La vitrine lenticulaire — Le sandwich verre / lenticulaire / verre

## LV-VL-FIG-03 · rév. 1 · 24-09-26 · ESQUISSE · schéma légendé en français


PROJET

## LES VEILLEURS — Beaufort 27

ARTISTE · MAÎTRE D'ŒUVRE

## Eva L'Hoest · +32 495 57 92 12 · eva.lhoest@gmail.com

ASSISTANT ÉLECTROMÉCANIQUE

## Gioacchino Miceli · +32 497 84 45 10 · gioacchino.miceli@thefaktory.com

DOCUMENT

## La vitrine lenticulaire — Le sandwich verre / lenticulaire / verre

OBJET

## Double vitrage démontable, lenticulaire libre, châssis U inox

N° DOCUMENT · RÉVISION · DATE · HEURE

## LV-VL-FIG-03 · rév. 1 · 24-09-26

STATUT

## ESQUISSE

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

Les Veilleurs — La vitrine lenticulaire — Circuit d'air sec, poche d'équilibrage et dessiccant

## LV-VL-FIG-04 · rév. 1 · 24-09-26 · ESQUISSE · schéma légendé en français


PROJET

## LES VEILLEURS — Beaufort 27

ARTISTE · MAÎTRE D'ŒUVRE

## Eva L'Hoest · +32 495 57 92 12 · eva.lhoest@gmail.com

ASSISTANT ÉLECTROMÉCANIQUE

## Gioacchino Miceli · +32 497 84 45 10 · gioacchino.miceli@thefaktory.com

DOCUMENT

## La vitrine lenticulaire — Circuit d'air sec, poche d'équilibrage et dessiccant

OBJET

## Double vitrage démontable, lenticulaire libre, châssis U inox

N° DOCUMENT · RÉVISION · DATE · HEURE

## LV-VL-FIG-04 · rév. 1 · 24-09-26

STATUT

## ESQUISSE

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

# Les Veilleurs — La vitrine lenticulaire — Séquence de montage

## LV-VL-FIG-05 · rév. 1 · 24-09-26 · ESQUISSE · schéma légendé en français


PROJET

## LES VEILLEURS — Beaufort 27

ARTISTE · MAÎTRE D'ŒUVRE

## Eva L'Hoest · +32 495 57 92 12 · eva.lhoest@gmail.com

ASSISTANT ÉLECTROMÉCANIQUE

## Gioacchino Miceli · +32 497 84 45 10 · gioacchino.miceli@thefaktory.com

DOCUMENT

## La vitrine lenticulaire — Séquence de montage

OBJET

## Double vitrage démontable, lenticulaire libre, châssis U inox

N° DOCUMENT · RÉVISION · DATE · HEURE

## LV-VL-FIG-05 · rév. 1 · 24-09-26

STATUT

## ESQUISSE

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

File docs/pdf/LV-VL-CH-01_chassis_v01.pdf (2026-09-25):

# Les Veilleurs — La vitrine lenticulaire — Châssis v01 U 80×40×5 316L — trois vues

## LV-VL-CH-01 · rév. 1 · 25-09-26 · ÉTUDE · schéma légendé en français


PROJET

## LES VEILLEURS — Beaufort 27

ARTISTE · MAÎTRE D'ŒUVRE

## Eva L'Hoest · +32 495 57 92 12 · eva.lhoest@gmail.com

ASSISTANT ÉLECTROMÉCANIQUE

## Gioacchino Miceli · +32 497 84 45 10 · gioacchino.miceli@thefaktory.com

DOCUMENT

## La vitrine lenticulaire — Châssis v01 U 80×40×5 316L — trois vues

OBJET

## Double vitrage démontable, lenticulaire libre, châssis U inox

N° DOCUMENT · RÉVISION · DATE · HEURE

## LV-VL-CH-01 · rév. 1 · 25-09-26

EN LIGNE

### https://vitrine-lenticulaire.vercel.app

STATUT

## ÉTUDE

© Eva L'Hoest 2026 — Confidentiel. Reproduction, diffusion ou usage hors de cette consultation interdits sans accord écrit de l'artiste. Cotes non contractuelles.

1 / 1

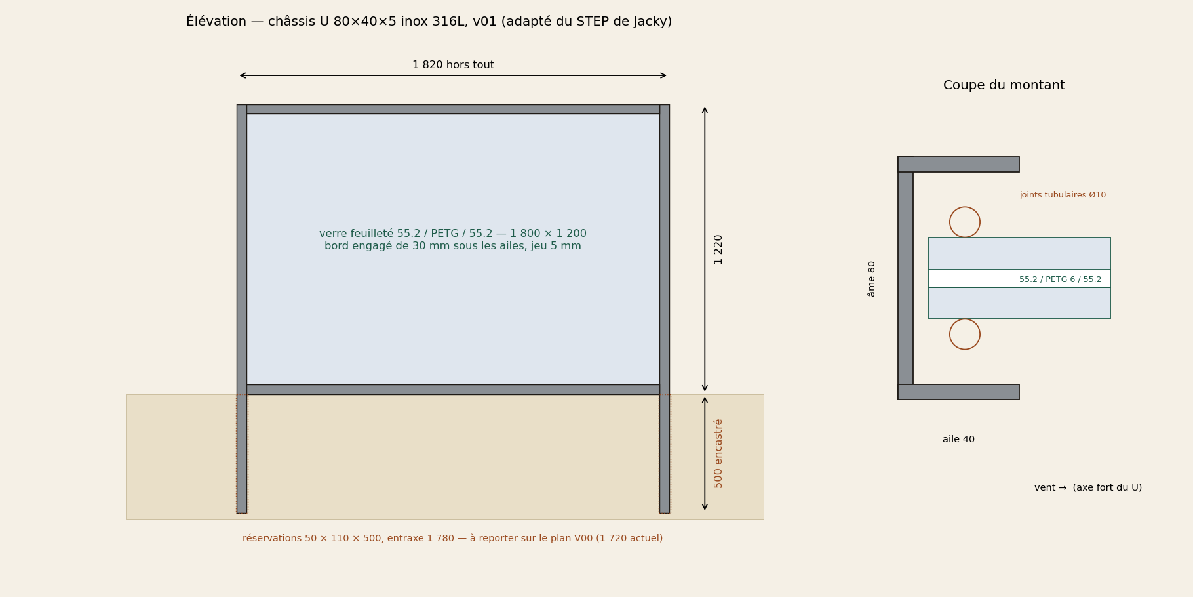
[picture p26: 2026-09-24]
img/chassis_v01_U80x40.png

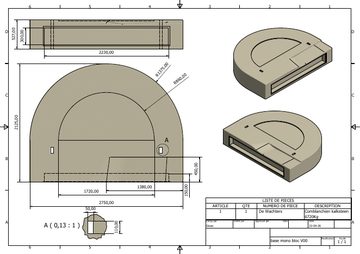
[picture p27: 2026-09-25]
docs/thumbs/base_V00.jpg

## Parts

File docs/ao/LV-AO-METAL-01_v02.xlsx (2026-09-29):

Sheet: Ateliers
LV-AO-METAL-01 — Ateliers consultés (lots 2a aquarium / 2b châssis)
Coordonnées relevées le 29-09-2026 sur les sites des ateliers. Note 0 = écarté (pas d'adresse publiée ou hors propos), 5 = à prendre. Vague 1 = 12 ateliers (6 aquarium, 6 châssis). Cellules jaunes = à compléter.
Réf. | Atelier | Lot | Vague | Langue | Ville (pays) | Site web | E-mail | Téléphone | Spécialité | Remarque | Note Pierre 0–5 (29-09) | Motif si écarté | Contact nominatif
A01 | Inoxytech ICRB bv | 2a Aquarium | Vague 1 | NL | Kuurne (BE) | https://www.inoxytech.be | info@inoxytech.be | +32 56 43 93 93 | Structures inox sur mesure (pharma, horeca, agroalimentaire, construction) | Identification sûre | 2
A02 | Ateliers Emile Meurice SRL | — | Écarté | FR | Montignies-sur-Sambre (BE) | https://www.ateliers-meurice.be | info@ateliers-meurice.be | +32 71 30 72 19 | Usinage de précision, soudure, traitement thermique ; travaille l'inox | Atelier de mécanique plus que chaudronnerie — vérifier que c'est bien le Meurice visé | 0 | hors propos → 0
A03 | Ateliers Charles Webber SRL | — | Écarté | FR | Châtelineau (BE) | https://www.chaudronnerie-webber.be | formulaire de contact | +32 71 38 42 59 | Construction métallique et chaudronnerie, cuves inox, montage sur site | Pas d'e-mail publié | 0 | pas d'adresse e-mail publiée → 0 (note initiale 1)
A04 | B.M.C. Inox (BMCI) | 2a Aquarium | Vague 1 | FR | Saint-Martin-Boulogne (FR) | https://www.bmc-inox.fr | contact@bmc-inox.fr | +33 6 50 83 36 94 | Chaudronnerie inox agroalimentaire et industrielle, soudure sous azote | Pas-de-Calais, ~1 h de Westende | 2
A05 | ADCL Industries | 2a Aquarium | Vague 1 | FR | Dunkerque (FR) | https://adcl-industries.fr | contact@adcl-industries.fr | +33 3 28 51 10 46 | Découpe jet d'eau, pliage, ensembles mécano-soudés acier/inox (chimie, maritime) | Nord, proche de la côte | 1
A06 | KAIROS Maintenance et solutions industrielles | — | Écarté | FR | Calais (FR) | https://www.kairos-hdf.com | formulaire de contact | +33 3 21 96 07 28 | Chaudronnerie-métallerie acier/inox : cuves, châssis, garde-corps | Pas d'e-mail publié | 0 | hors propos → 0
A07 | Scheepswerf IDP NV (IDP Shipyard) | — | Écarté | NL | Oostende (BE) | https://www.idp-shipyard.be | idp@idp-shipyard.be | +32 59 32 18 64 | Chantier naval, ateliers mécanique et chaudronnerie | Plutôt réparation navale | 0 | hors propos → 0
A08 | ConceptInox SRL | — | Écarté | FR | La Bruyère (BE) | https://conceptinox.be | formulaire de contact | +32 478 95 68 72 | Créations inox sur mesure : garde-corps, mobilier, polissage | Petit atelier artisanal | 0 | pas d'adresse e-mail publiée → 0 (note initiale 3)
A09 | Metaalwerken Vanthuyne NV | 2a Aquarium | Vague 1 | NL | Nieuwpoort (BE) | https://www.vanthuynenv.be | info@vanthuynenv.be | +32 58 23 78 84 | Constructions métal, inox, alu ; tôlerie, tournage-fraisage | Identification probable ; à 10 km de Westende | 3
C01 | Ateliers Melens & Dejardin SRL | 2b Châssis | Vague 1 | FR | Jupille-sur-Meuse (BE) | https://www.melensdejardin.be | secretariat@melensdejardin.be | +32 4 362 62 20 | Chaudronnerie industrielle, architecture, art ; pièces sur mesure jusqu'à 8 m | Depuis 1932 ; expérience œuvres d'art | 4
C02 | Moker BV (Metaalkreaties) | — | Écarté | NL | Boom (BE) | https://www.moker.be | formulaire de contact | +32 3 888 96 86 | Metaalatelier art, architecture, design (acier, inox, alu) | Coordonnées via Infosteel, à confirmer | 0 | pas d'adresse e-mail publiée → 0 (note initiale 2)
C03 | Metaalcomfort BVBA | 2b Châssis | Vague 1 | NL | Oostende (BE) | https://www.metaalcomfort.be | info@metaalcomfort.be | +32 59 80 54 60 | Métallerie sur mesure acier/alu/inox : escaliers, balustrades | À 15 km de Westende | 3
C04 | Prosoudure SRL | 2a Aquarium | Vague 1 | FR | Verlaine (BE) | https://www.prosoudure.be | info@prosoudure.be | +32 498 27 64 41 | Construction métallique inox/acier, tôlerie, découpe laser ; EN 1090-2 | Certifié EN 1090-2 | 3
C05 | MV Soudure | 2b Châssis | Vague 1 | FR | Ghlin / Mons (BE) | https://www.mvsoudure.be | info@mvsoudure.be | +32 491 24 96 26 | Ferronnerie-métallerie : garde-corps, escaliers, découpe CNC |  | 2
C06 | Made in Inox BV | — | Écarté | NL | Poperinge (BE) | https://www.madeininox.be | formulaire de contact | +32 57 38 81 04 | Métallerie inox sur mesure : escaliers, châssis, art | Forge depuis 1878 ; téléphone à confirmer | 0 | pas d'adresse e-mail publiée → 0 (note initiale 3)
C07 | Tecno Art BV | — | Écarté | NL | Kalmthout (BE) | https://tecnoart.be | formulaire de contact | +32 3 651 44 84 | Constructions acier pour espace public, mobilier urbain | Néerlandophone (pas FR) | 0 | pas d'adresse e-mail publiée → 0 (note initiale 2)
C08 | Atelier de Ferronnerie Degueldre SRL | 2b Châssis | Vague 1 | FR | Hermalle-sous-Huy (BE) | https://atelierdegueldre.be | info@atelierdegueldre.be | +32 85 41 21 23 | Ferronnerie sur mesure : escaliers, garde-corps, Corten |  | 3
C09 | Luc Martin Soudure | 2a Aquarium | Vague 1 | FR | Louveigné (BE) | https://www.lucmartinsoudure.be | inoxmartin@gmail.com | +32 474 94 06 01 | Construction métallique, TIG/MIG, inox ; EN 1090 | Sur rendez-vous | 3
C10 | La Manufacture du Métal | 2b Châssis | Vague 1 | FR | Noyelles-lès-Seclin (FR) | https://manufacture-metal.fr | cb@manufacture-metal.fr | +33 3 20 32 19 65 | Métallerie d'agencement et d'architecture : acier, inox, laiton |  | 3
C11 | D'ART Design | 2b Châssis | Vague 1 | FR | Steenwerck (FR) | https://dartdesign.fr | Julien@dartdesign.fr | +33 6 03 33 38 95 | Métallerie design : garde-corps, verrières, portails | Petite structure ; intervient en Belgique | 3

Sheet: Suivi
LV-AO-METAL-01 — Suivi des demandes d'offre
Jaune = à remplir le jour même de l'envoi / du retour. Relance = date d'envoi + 10 jours (formule). Montant en € HT, hors transport sauf mention. Code lien 3D = suffixe &a=XXX du lien maquette dans le mail ; ouvertures visibles sur stat-les-veilleurs (code STAT).
Réf. | Atelier | Lot | Langue | Contact | Date d'envoi | Relance (J+10) | Réponse (date) | Montant € HT | Délai (semaines) | Décision | Remarques | Code lien 3D | 3D ouverte (stat)
A01 | Inoxytech ICRB bv | 2a Aquarium | NL | info@inoxytech.be |  |  |  |  |  | à envoyer |  | INX
A04 | B.M.C. Inox (BMCI) | 2a Aquarium | FR | contact@bmc-inox.fr |  |  |  |  |  | à envoyer |  | BMC
A05 | ADCL Industries | 2a Aquarium | FR | contact@adcl-industries.fr |  |  |  |  |  | à envoyer |  | ADC
A09 | Metaalwerken Vanthuyne NV | 2a Aquarium | NL | info@vanthuynenv.be |  |  |  |  |  | à envoyer |  | VAN
C01 | Ateliers Melens & Dejardin SRL | 2b Châssis | FR | secretariat@melensdejardin.be | 2026-09-29 | 2026-10-09 |  |  |  | envoyé | envoyé depuis Gmail (sans pixel Superhuman) ; lien 3D sans code | MEL
C03 | Metaalcomfort BVBA | 2b Châssis | NL | info@metaalcomfort.be |  |  |  |  |  | à envoyer |  | MTC
C04 | Prosoudure SRL | 2a Aquarium | FR | info@prosoudure.be |  |  |  |  |  | à envoyer |  | PRO
C05 | MV Soudure | 2b Châssis | FR | info@mvsoudure.be |  |  |  |  |  | à envoyer |  | MVS
C08 | Atelier de Ferronnerie Degueldre SRL | 2b Châssis | FR | info@atelierdegueldre.be |  |  |  |  |  | à envoyer |  | DEG
C09 | Luc Martin Soudure | 2a Aquarium | FR | inoxmartin@gmail.com |  |  |  |  |  | à envoyer |  | LMA
C10 | La Manufacture du Métal | 2b Châssis | FR | cb@manufacture-metal.fr |  |  |  |  |  | à envoyer |  | MDM
C11 | D'ART Design | 2b Châssis | FR | Julien@dartdesign.fr |  |  |  |  |  | à envoyer |  | DAD
 | Envoyés |  |  |  | 1
 | Offres reçues |  |  |  | 0
 | À relancer aujourd'hui |  |  |  | 0

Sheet: Comparaison
LV-AO-METAL-01 — Grille de comparaison des offres
Montant et délai sont repris automatiquement de l'onglet Suivi. Les colonnes techniques (jaune) se remplissent à la lecture de l'offre : O / N / partiel, ou une note courte.
Réf. | Atelier | Lot | Montant € HT | Délai (sem.) | Écart au moins-disant | Nuance 316L confirmée | Certificat matière 3.1 | Essai / recette prévu | Transport et pose inclus | Garantie 10 ans | Conformité au cahier | Points ouverts | Note globale (1-5)
A01 | Inoxytech ICRB bv | 2a Aquarium
A04 | B.M.C. Inox (BMCI) | 2a Aquarium
A05 | ADCL Industries | 2a Aquarium
A09 | Metaalwerken Vanthuyne NV | 2a Aquarium
C01 | Ateliers Melens & Dejardin SRL | 2b Châssis
C03 | Metaalcomfort BVBA | 2b Châssis
C04 | Prosoudure SRL | 2a Aquarium
C05 | MV Soudure | 2b Châssis
C08 | Atelier de Ferronnerie Degueldre SRL | 2b Châssis
C09 | Luc Martin Soudure | 2a Aquarium
C10 | La Manufacture du Métal | 2b Châssis
C11 | D'ART Design | 2b Châssis
 | Moins-disant 2a Aquarium
 | Moins-disant 2b Châssis
 | Colonne E des lignes de synthèse = montant moyen du lot.

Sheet: Légende
Fichier | LV-AO-METAL-01 — appels d'offres menuiserie métallique, Les Veilleurs (Eva L'Hoest, Beaufort 27)
Lots | 2a = aquarium (caisson inox 316L, couvercle, joint, essai) · 2b = châssis de l'écran (tube 80×40×3 316L, 1 890 hors tout, montants 1 728 dont 528 encastrés)
Courrier | Modèle validé le 29-09-2026 (FR/EN/NL) : voix d'Eva, contact Gioacchino seul, signature Production Office ajoutée par Gmail ; expéditeur eva.production.bx@gmail.com ; liens = Drive de l'item + maquette 3D
Règle | Un seul item par atelier au premier contact ; le second item lui est proposé plus tard si le courant passe
Onglet Ateliers | 20 ateliers repérés, notés de 0 à 5 par Pierre le 29-09-2026 ; 12 en vague 1 (6 aquarium, 6 châssis), 8 écartés (lignes grises : pas d'adresse publiée ou hors propos)
Onglet Suivi | Une ligne par envoi ; consigner le jour même. Relance calculée à J+10. Décision : liste déroulante
Onglet Comparaison | Grille unique par lot ; montant et délai repris du Suivi ; colonnes techniques à remplir à la lecture des offres
Cellules jaunes | À remplir
Signature des courriers | Eva L'Hoest (artiste, maître d'œuvre) ; Gioacchino Miceli (assistant électromécanique)
Sources contacts | Sites des ateliers, Infosteel, annuaires (Cylex, Kompass) — relevé du 29-09-2026

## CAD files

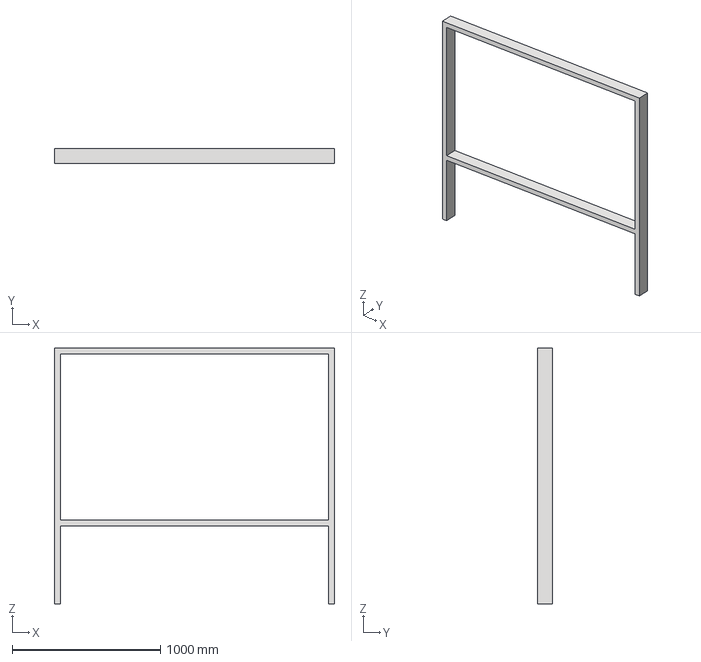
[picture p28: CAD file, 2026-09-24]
docs/cao/ecran_v00_100x40x3.stp
1890.0 x 100.0 x 1727.8 mm

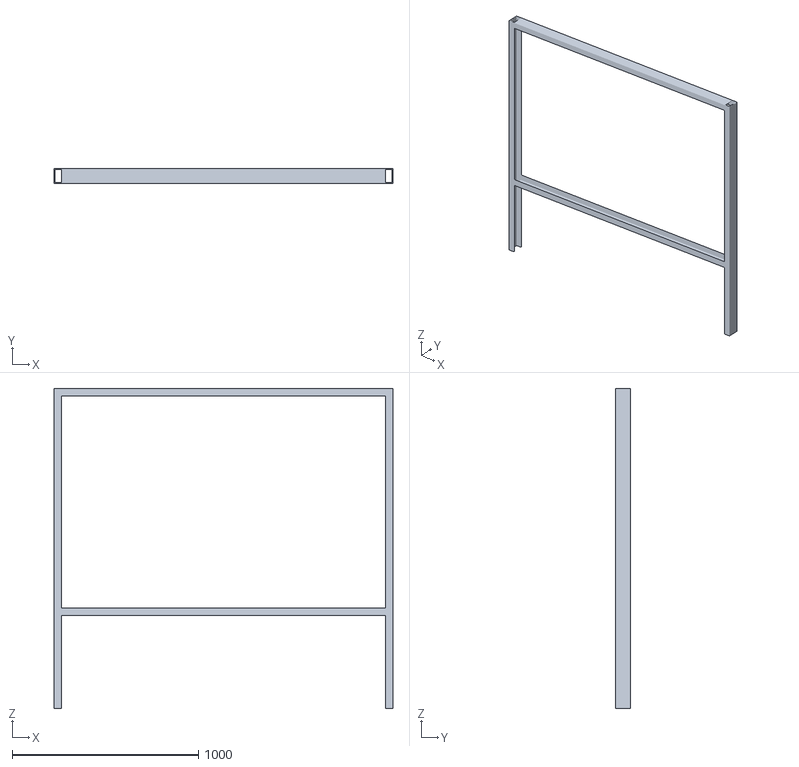
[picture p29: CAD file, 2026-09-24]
docs/cao/ecran_v01_U80x40.stl
1820.0 x 80.0 x 1720.0

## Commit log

2026-09-24 Vitrine lenticulaire v0.1 : note de principe, schémas, fournitures, STEP Jacky, châssis v01 et note vent
    [ecran_v00_100x40x3.stp, ecran_v01_U80x40.stl]
2026-09-25 v0.2 — charte commune, 4 langues, documents avec vignettes, PDF cartouchés
2026-09-25 analytique : base Supabase la-vigie branchée
2026-09-29 docs/ao: dossiers d'appel d'offres lots 2a/2b (châssis v02 tube 80x40x3, recueils de plans FR/EN, plans base)
2026-09-29 tableur LV-AO-METAL-01 v02 (notes Pierre, 12 ateliers, codes lien 3D)
    [LV-AO-METAL-01_v02.xlsx]
2026-09-29 dossiers de consultation : « au moins dix ans » (aquarium v02.4 FR/EN/NL/DE, châssis v01.1 FR/EN)
2026-09-30 Accès : mot de passe du projet vérifié côté serveur (api/gate, lv_gate_ao), code PLH conservé ; liens ?code=EVA inchangés
    Claude-Session: https://claude.ai/code/session_01JMWesNPqRLzRhUjG23ndV6
